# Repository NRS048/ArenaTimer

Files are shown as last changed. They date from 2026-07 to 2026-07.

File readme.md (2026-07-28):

Below this point is likely AI generated, do not trust what is said, many physical features are promised on the PCB but are not at all implemented in the codebase. -N

---

# ⏱️ Event Match Timer & Lockout System

An open-source, ESP32-based event and match timer platform featuring wireless remote integration, with web interface.

---

## 🚀 Getting Started

### 1. Hardware Orientation & Powering
* **Orientation Flexibility:** The timer can be configured to operate in either horizontal orientation. If your mounting or power cable strategy requires it, you can flip the included hanging bracket to the opposite side and enable **Invert Display** in the web settings to route the power cable from above.
* **Power Requirements:** Connect the timer using the provided power supply. 
> ⚠️ **CRITICAL:** Only use **5V** power supplies capable of delivering at least **60W**. Applying a voltage higher than 5V will **permanently damage** the hardware.

### 2. Initial Wi-Fi & Web UI Setup
1. **Boot Sequence:** Upon power-up, the display initializes with dashes (`--:--`) and the border will blink, indicating it is attempting to connect to the last saved Wi-Fi network.
2. **Access Point (AP) Mode:** If the network is unavailable (or during first-time setup), the timer switches to AP mode, broadcasting its own network:
   * **SSID:** `MACROTimer`
   * **Password:** `MACROTimerPassword`
   * Example Username & Password
3. **Connecting to the UI:** * Connect your phone, tablet, or computer to the `TimerSetup` network.
   * Locate the timer's IP address in your device's network connection settings (this process varies by operating system).
   * Open a web browser and enter the IP address to access the control interface.

<p align="center">
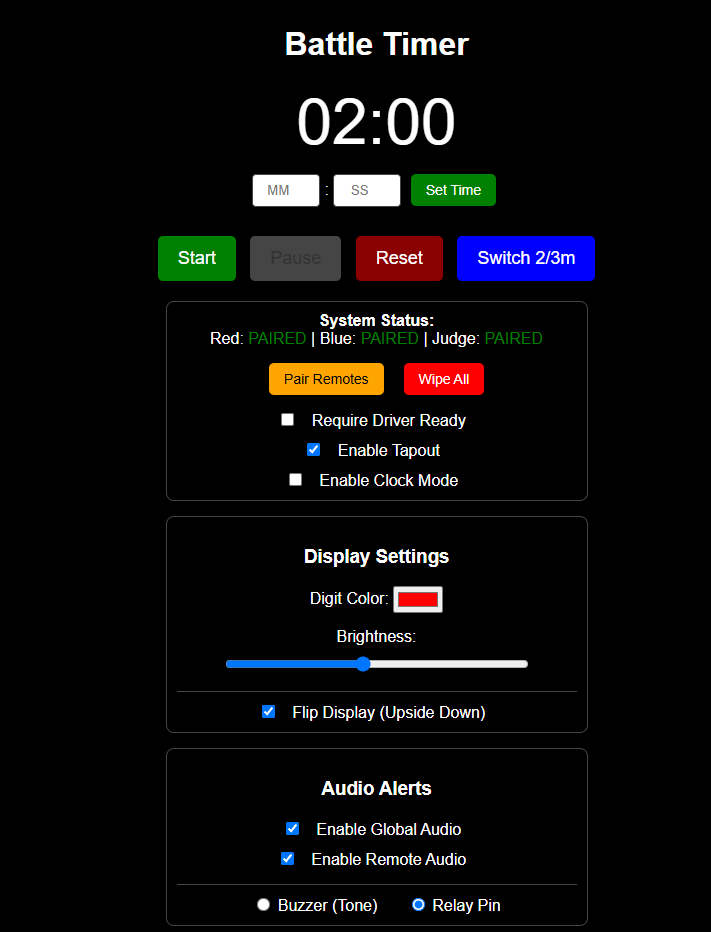
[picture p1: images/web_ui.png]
Web Control Interface Dashboard
  
</p>

*Note: The local AP interface is identical to the network interface. If no external Wi-Fi network is available at your venue, you can run the timer in this standalone mode completely offline.*

4. **Station Mode (Optional):** To connect the timer to an existing venue Wi-Fi network, use the configuration section at the bottom of the webpage to save your local **SSID** and **Password**.

<p align="center">
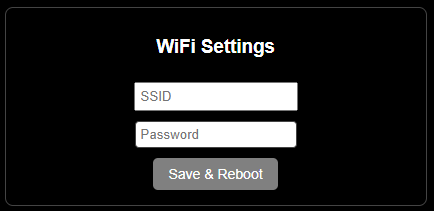
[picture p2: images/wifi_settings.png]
  
</p>

---

## ⚙️ Configuration & Features

### 🎮 Wireless Remotes & Pairing
The system supports three battery-powered wireless remotes: **one Main Controller** and **two Driver Ready/Tap-Out buttons** (Red vs. Blue).

<p align="center">
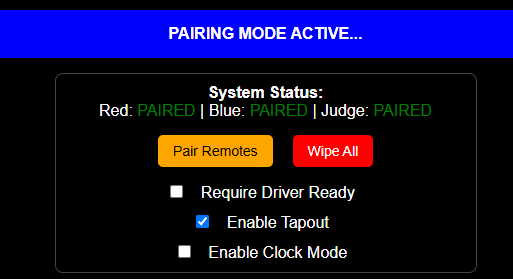
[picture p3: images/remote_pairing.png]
  
</p>

* **Pairing Procedure:** Remotes must be paired before deployment. Click **Pair Remote** in the Web UI to enter binding mode, turn on the remote, and press any button. The timer will automatically exit binding mode, and the Web UI status will update to `Paired`. Repeat independently for each remote.
* **Driver Ready Lockout:** Enabling the `Require Driver Ready` checkbox prevents a match from starting until both driver remotes register a "Ready" state. 
  * *Visual Indicators:* The physical white border indicates overall readiness. Individual Red/Blue illumination confirms when each respective driver has ready-ed up.
* **Tap-Out Functionality:** Even if the pre-match lockout is disabled, the driver remotes function by default as tap-out indicators. Pressing them during a match triggers a unique tap-out animation and audio effect (can be toggled off via the checkbox).

### 🔊 Audio Options
* **Global Toggle:** Easily enable or disable all system audio via the web panel.
* **Output Routing:** Switch between the onboard piezo beeper or a dedicated **relay output** used to switch larger external horn circuits, PA systems, or specialized lighting.
* **Attention Horn:** The Main Controller features a dedicated button to manually trigger the sound effects to grab the attention of competitors or spectators.

### 🔒 Operational Lockout
To prevent accidental mid-match disruption, most configuration options, adjustments, and web buttons are **automatically disabled** while the timer is actively running.

---

## 🛠️ Assembly Process (Electronics Kits)

For users assembling the hardware from the DIY electronics kits, follow this general framework. Refer to the project `BOM.md` for exact hardware sizing, screw counts, and component sourcing links.

### 1. 3D Printed Frame Selection
Choose the frame variant that best fits your 3D printer's build volume:
* **Small Printers:** Cut down to fit standard build plates. Requires more assembly hardware and time but maximizes accessibility.
* **Medium Printers (H2s/H2d Optimized):** A balanced approach featuring lower part counts and optimized print times.
* **Large Printers:** Designed specifically for large-format platforms like the *Elegoo Orange Storm Giga*. 

### 2. Print Settings & Materials
* **Main Frame:** Print in **PETG** for superior mechanical strength and thermal resilience during high-temperature transport or storage.
  * **Walls:** 4–6 perimeters
  * **Infill:** 15–25% Gyroid
* **Lenses:** All frame variations share the same lens files. Print them with enough top/bottom layers to ensure the front face prints **completely solid** to optimize light diffusion and visual clarity.

---

## 🧠 Advanced Development & Limitations

### 📡 RF Limitations & Best Practices
The timer utilizes an **ESP32** module with a printed trace antenna, while the remotes utilize **ESP8266** modules (also with printed antennas). 
* **Range & Interference:** While highly reliable in tested arena layouts (e.g., SEMO), performance can degrade at extreme distances or in environments experiencing heavy 2.4 GHz spectrum congestion (crowded Wi-Fi, heavy radio traffic).
* **Upgrades:** If your venue demands extreme range, the hardware can be modified to use variants featuring external SMA antennas. Reach out if you need assistance engineering a solution.
* **Multi-Timer Sync:** You can pair a single set of remotes to multiple timers simultaneously by repeating the pairing process on each unit. A native web-based synchronization protocol is currently on the feature roadmap.

### 💻 Firmware Upgrades & Exposed I/O
* **Over-The-Air (OTA) Updates:** Firmware updates can be flashed seamlessly without opening the enclosure. Navigate to `http://<your-timer-ip>/update` to access the **ElegantOTA** interface, where you can drag-and-drop compiled `.bin` updates.
* **Hardware Expansion:** Additional I/O pins are deliberately exposed near the internal ESP32 module. Advanced users can open the case and solder directly to these lines to integrate custom addressable LED strips, sensors, or physical inputs.

### ⚡ ESD Precautions & LED Repair
> ⚡ **CAUTION:** The internal PCBs contain components sensitive to Electrostatic Discharge (ESD). Handle bare board assemblies with care during assembly or modifications.

* **Common Failure Mode:** If an ESD event occurs, a single addressable LED in the display chain may burn out. Because the LEDs are wired in series, **if one LED fails, all subsequent data down the chain is blocked**, causing the rest of the display past that point to drop out. 
* **Support:** If you experience an LED failure during assembly or firmware hacking, reach out—these are repairable, and I can guide you through jumping or replacing the compromised pixel. Note that failures have only occurred during loose bench development; fully enclosed units have proven resilient during regular live event usage.

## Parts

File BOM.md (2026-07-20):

# Bill of Materials (BOM)

This document contains the component lists for building the Double-Sided Timer, Single-Sided Timer, Driver Ready Remotes, and Timer Controller. 

*Note: For a **Single-Sided Timer**, you can use the Double-Sided BOM but simply cut the quantities for the display housing, lenses, hardware, and PCBs in half.*

---

## 1. Double-Sided Timer

### 3D Printed Parts
*   **Timer Housing Parts:** 2 full sets (1 set = 1 Left + 1 Right). *PETG recommended, but any material/color works.*
*   **Lenses:** 2 full sets. *PETG recommended for transparency. Each set includes 4 digits, 4 borders, and 2 colons.*
*   **Joiner Blocks:** 4x
*   **Mounting Bracket:** 1x (Optional)

### Hardware & Mechanical
| Component | Qty | Notes / Link |
| :--- | :---: | :--- |
| PCB Mounting Screws | 24+ | 12 per side minimum. [Amazon](https://a.co/d/00hEOAHO) |
| Housing Screws for Joiner Blocks | 16-24 | [Amazon](https://a.co/d/06CnOLYg) |

### Electronics & PCBA
The system uses **4 Display PCBs** ordered from JLCPCB (Black solder mask, full assembly per the PCB BOM found in the `hardware` folder). 

**Only 1 of the 4 PCBs needs to be fully populated** with the ESP32, relay, beeper, screw terminals, and power connector based on your needs. The audio/relay parts are completely optional.

| Component | Qty | Description / Source |
| :--- | :---: | :--- |
| **ESP32 Development Board** | 1 | Main controller board. [Amazon](https://a.co/d/0hX7Juhc) |
| **Power Connector** | 1 | Same Sky PJ-082BH. [DigiKey](https://www.digikey.com/en/products/detail/same-sky-formerly-cui-devices/PJ-082BH/3477156) |
| **AC/DC Power Adapter** | 1 | 5V, 60W minimum. [Amazon](https://a.co/d/0fynI0mL) |
| **Beeper** (Optional) | 1 | Same Sky CEM-1203-42. [DigiKey](https://www.digikey.com/en/products/detail/same-sky-formerly-cui-devices/CEM-1203-42/412412) |
| **Relay** (Optional) | 1 | Omron/Aratas G5V-2-DC5. [DigiKey](https://www.digikey.com/en/products/detail/aratas-america-llc/G5V-2-DC5/87819) |
| **Screw Terminals** (Optional) | Var | For relay output. Phoenix Contact [socket](https://www.digikey.com/en/products/detail/phoenix-contact/1757255/260475) or [plug](https://www.digikey.com/en/products/detail/phoenix-contact/1757022/260380) |
| **16 AWG Wire** | ~2 ft | For connecting power between the two display sides. |
| **22 AWG Wire** | ~2 ft | For routing signals (`BOUT` > `BIN`, `DOUT` > `DIN`) to the second board. |

---

## 2. Driver Ready Remotes (Qty: 2)

The remote PCBAs are ordered as bare boards. To save costs, manually solder the headers/sockets that come included with the ESP8266 boards. The button circuit is simple and just shorts the `RST` pin of the ESP8266 to ground—this can easily be adapted to larger arcade buttons if desired.

### 3D Printed Parts
*   **Printed Housing:** 2x
*   **Printed Rear Cover:** 2x

### Components
| Component | Qty | Description / Source |
| :--- | :---: | :--- |
| **ESP8266 Board** | 2 | NodeMCU / D1 Mini style. [Amazon](https://a.co/d/02HlLmq1) |
| **Tactile Buttons** | 2 | Same Sky TS14-1212. [DigiKey](https://www.digikey.com/en/products/detail/same-sky-formerly-cui-devices/TS14-1212-120-BK-260-SCR-D/16562671) |
| **Button PCBs** | 2 | Custom bare boards (or custom wiring setup). |
| **Battery Pack** | 2 | Portable power source. [Amazon](https://a.co/d/02QkeaG8) |

---

## 3. Timer Controller

The controller PCBA uses the custom PCB fabrications ordered bare from JLCPCB using the Gerber files located in the `hardware` folder.

### 3D Printed Parts
*   **Printed Housing:** 1x
*   **Printed Rear Cover:** 1x

### Components
| Component | Qty | Description / Source |
| :--- | :---: | :--- |
| **ESP8266 Board** | 1 | NodeMCU / D1 Mini style. [Amazon](https://a.co/d/02HlLmq1) |
| **Tactile Buttons** | 5 | Same Sky TS14-1212. [DigiKey](https://www.digikey.com/en/products/detail/same-sky-formerly-cui-devices/TS14-1212-120-BK-260-SCR-D/16562671) |
| **Controller PCB** | 1 | Custom bare board. |
| **Battery Pack** | 1 | Portable power source. [Amazon](https://a.co/d/02QkeaG8) |

---

## 4. Range Upgrades & Modifications (Optional)

If you need extended wireless range for large track configurations, consider the following modifications:

*   **2.4GHz External Antenna (Untested):** Swap out the standard ESP8266 for a [Wemos D1 Mini Pro with an external antenna connector](https://www.aliexpress.us/item/3256808837639555.html).
*   **LoRA Conversion:** If 2.4GHz ESP-NOW performance is insufficient for your environment, the system can be adapted to LoRA hardware, though this will require additional custom hardware and firmware modifications.

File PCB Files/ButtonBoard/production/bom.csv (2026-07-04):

Designator | Footprint | Quantity | Value | LCSC Part #
D1 | 0603 | 1 | Red | C2286
J1, J2 | PinSocket_1x08_P2.54mm_Vertical | 2 | Conn_01x08_Socket | C42431840
J9 | 2060-452_998-404 | 1 | WAGO | C2765055
R1 | 0603 | 1 | 470 | C23179
SW1 | SW_PUSH-12mm | 1 | START | C2888699
SW2 | SW_PUSH-12mm | 1 | PAUSE | C2888699
SW3 | SW_PUSH-12mm | 1 | RESET | C2888699
SW4 | SW_PUSH-12mm | 1 | TIME_SEL | C2888699
SW5 | SW_PUSH-12mm | 1 | BUZZER | C2888699

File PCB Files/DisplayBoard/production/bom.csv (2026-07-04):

Designator | Footprint | Quantity | Value | LCSC Part #
C1, C2, C3, C4, C5, C6, C7 | 0402 | 7 | 100nF | C14663
D1, D10, D11, D112, D113, D114, D115, D116, D117, D118, D12, D13, D14, D15, D154, D155, D156, D157, D158, D159, D16, D160, D17, D18, D19, D2, D20, D21, D22, D23, D238, D239, D24, D240, D241, D242, D243, D244, D245, D246, D247, D248, D249, D25, D250, D251, D252, D253, D254, D255, D256, D257, D258, D259, D26, D260, D261, D262, D263, D264, D265, D266, D267, D268, D269, D27, D270, D271, D272, D273, D274, D275, D276, D277, D278, D279, D28, D280, D281, D282, D283, D284, D285, D286, D287, D288, D289, D29, D290, D291, D292, D293, D294, D295, D296, D297, D298, D299, D3, D30, D300, D301, D302, D303, D304, D305, D306, D307, D308, D309, D31, D310, D311, D312, D313, D314, D315, D316, D317, D318, D319, D32, D320, D321, D322, D323, D324, D325, D326, D327, D328, D329, D33, D330, D331, D332, D333, D334, D335, D336, D337, D338, D339, D34, D340, D341, D342, D35, D36, D37, D38, D4, D5, D6, D7, D70, D71, D72, D73, D74, D75, D76, D77, D78, D79, D8, D80, D81, D82, D83, D9 | LED_WS2812B_PLCC4_5.0x5.0mm_P3.2mm | 171 | WS2812B | C2843785
D40 | D_SMA | 1 | 1N1007, SMA | C727081
D41 | D_SOD-323 | 1 | 1N4148WS, SOD323 | C2128
J1 | JST_EH_S2B-EH_1x02_P2.50mm_Horizontal | 1 | Blue ready-up | C19271377
J10 | JST_EH_S2B-EH_1x02_P2.50mm_Horizontal | 1 | Red ready-up | C19271377
J13, J14 | 2060-452_998-404 | 2 | WAGO | C2765055
J15, J16 | PinSocket_1x15_P2.54mm_Vertical | 2 | Conn_01x15_Socket | C124408
J2 | PinSocket_1x02_P2.54mm_Horizontal | 1 | Conn_01x02_Socket | C2897384
J3 | PinHeader_1x02_P2.54mm_Horizontal | 1 | Conn_01x02_Pin | C492410
J4 | PinHeader_1x04_P2.54mm_Horizontal | 1 | GND | C492412
J5 | PinHeader_1x04_P2.54mm_Horizontal | 1 | 5V | C492412
J6 | PinSocket_1x04_P2.54mm_Horizontal | 1 | GND | C2897386
J7 | PinSocket_1x04_P2.54mm_Horizontal | 1 | 5V | C2897386
J9 | JST_EH_S6B-EH_1x06_P2.50mm_Horizontal | 1 | Conn_01x06_Pin | C157919
Q1, Q2 | SOT-323_SC-70 | 2 | BSS138 | C5224267
R10, R2 | 0402 | 2 | 100K | C25530
R3, R4, R5, R6, R7, R8, R9 | 0402 | 7 | 10k | C25744

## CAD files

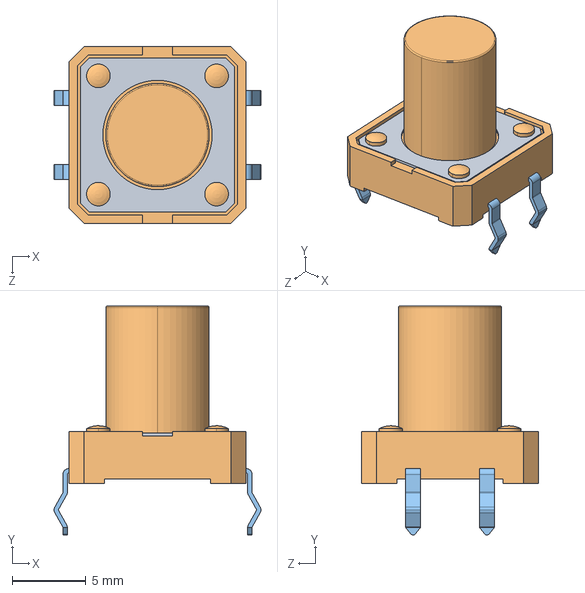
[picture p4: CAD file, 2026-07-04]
PCB Files/ButtonBoard/Same_Sky_TS14-1212-120-BK-260-SCR-D.step
14.0 x 15.5 x 12.0 mm

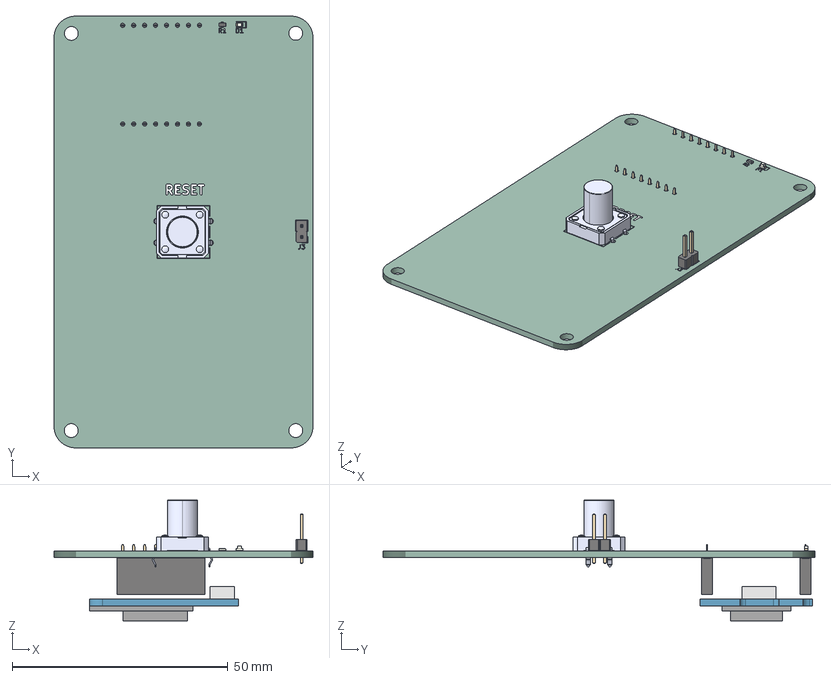
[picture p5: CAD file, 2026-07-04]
PCB Files/ReadyButtonBoard/ReadyButtonBoard.step
60.0 x 100.0 x 28.0 mm
PinHeader_1x02_P254mm_Vertical
LED_0603_1608Metric
CUI_DEVICES_TS14-1212-120-BK-260-SCR-D
R_0603_1608Metric
PinSocket_1x08_P2.54mm_Vertical x 2
wemos_d1_mini_light
ReadyButtonBoard_silkscreen x 2
ReadyButtonBoard_PCB

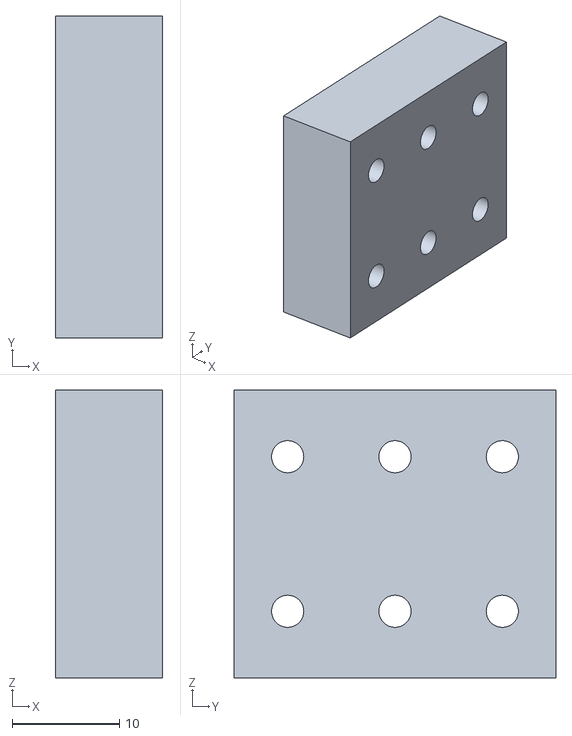
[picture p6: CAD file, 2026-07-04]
Print Files and Cad/Housing/Large Printer/Double_sided_mount.stl
10.00 x 30.0 x 26.8

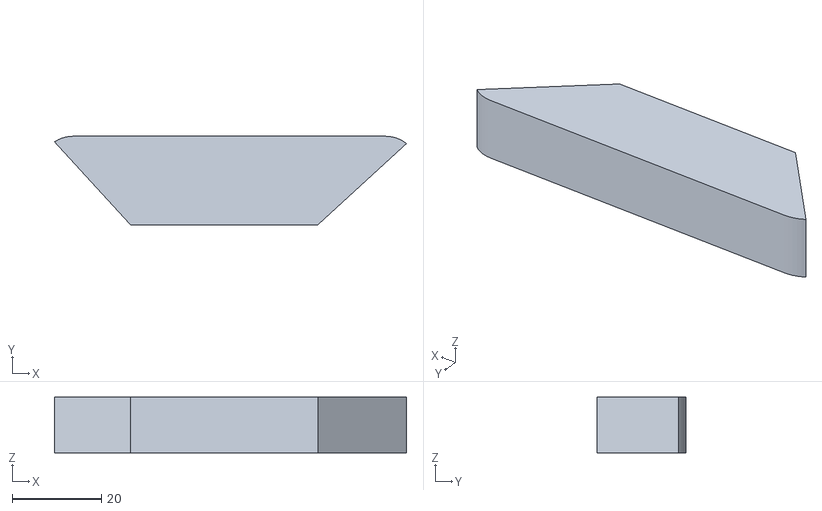
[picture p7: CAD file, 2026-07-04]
Print Files and Cad/Housing/Large Printer/Lenses/seg_d.stl
78.7 x 19.8 x 12.5

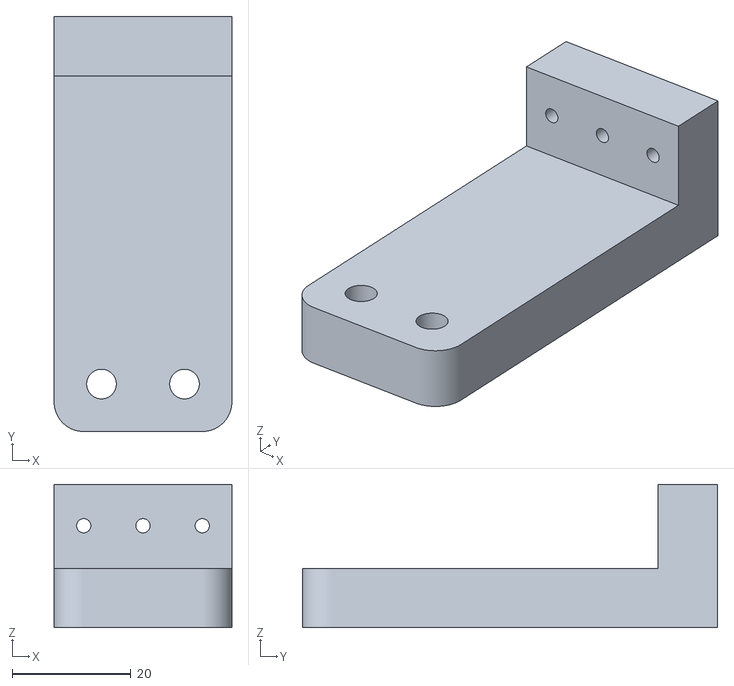
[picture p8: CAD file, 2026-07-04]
Print Files and Cad/Housing/Small Printer/Hanging_mount.stl
30.0 x 70.0 x 24.2

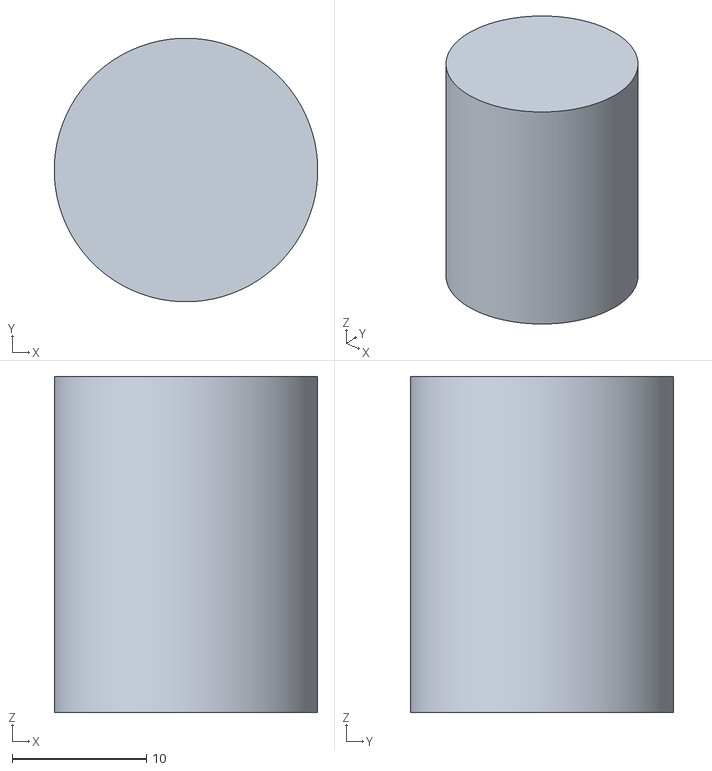
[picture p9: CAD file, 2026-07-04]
Print Files and Cad/Housing/Small Printer/Lenses/Colon_lens.stl
19.6 x 19.6 x 25.0

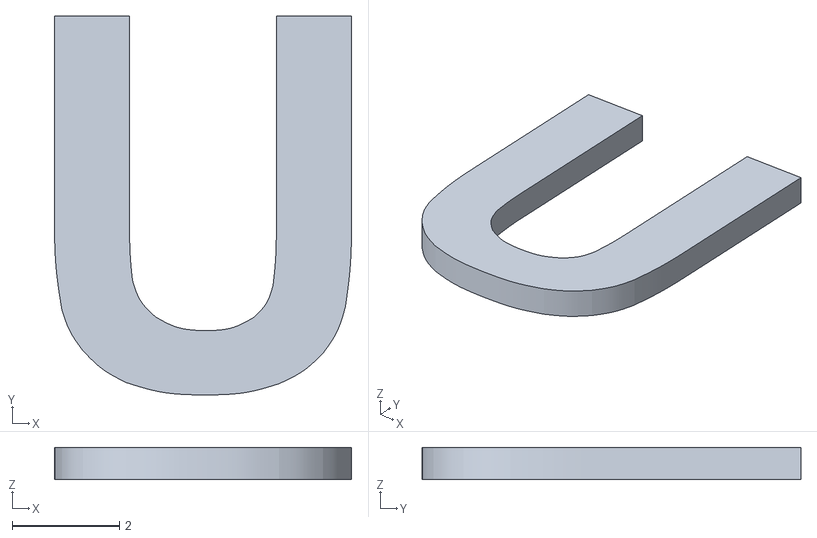
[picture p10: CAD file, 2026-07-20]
Print Files and Cad/Remotes/Controller/Timer Remote v22_Timer Remote v22_Body16.stl
5.54 x 7.06 x 0.6

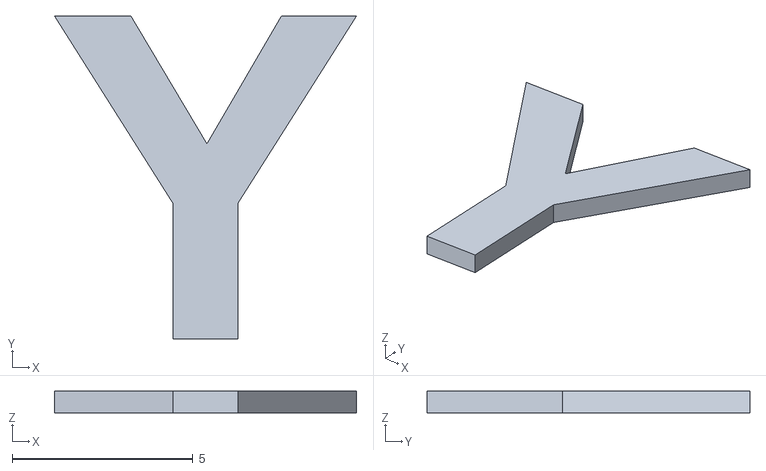
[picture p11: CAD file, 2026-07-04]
Print Files and Cad/Remotes/Driver Ready/Driver Ready Remote v2_Driver Ready Remote v2_Body19.stl
8.35 x 8.93 x 0.6

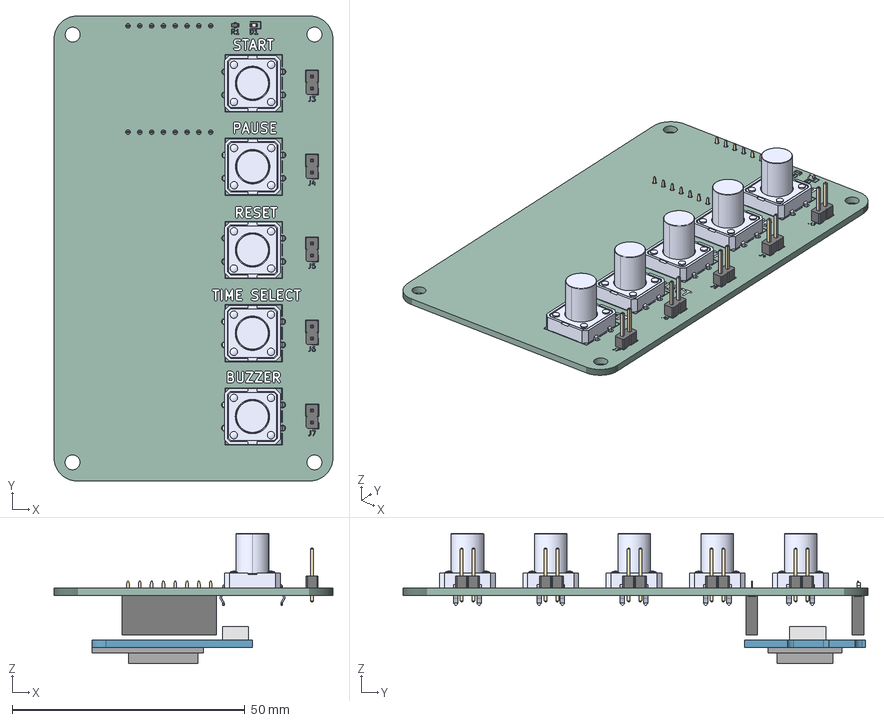
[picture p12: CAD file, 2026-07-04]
PCB Files/ButtonBoard/ButtonBoard.step
60.0 x 100.0 x 28.0 mm
PinHeader_1x02_P254mm_Vertical x 5
CUI_DEVICES_TS14-1212-120-BK-260-SCR-D x 5
LED_0603_1608Metric
R_0603_1608Metric
PinSocket_1x08_P2.54mm_Vertical x 2
wemos_d1_mini_light
ButtonBoard_silkscreen x 2
ButtonBoard_PCB

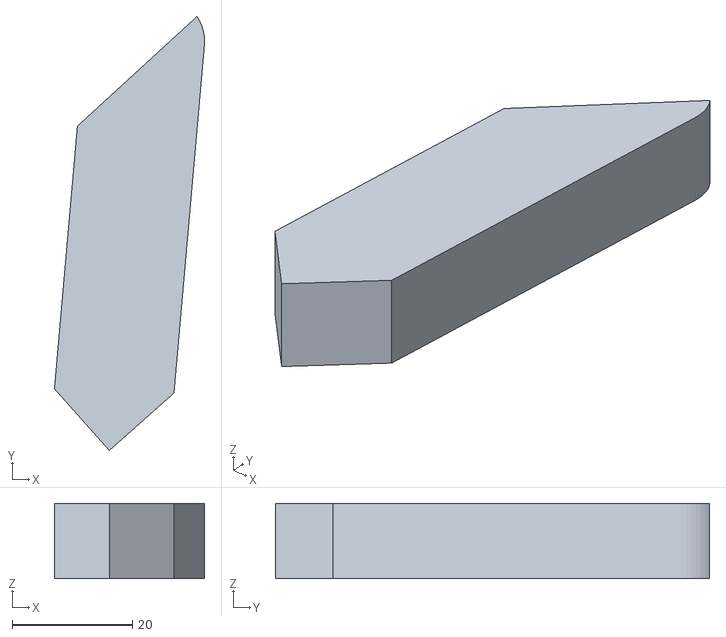
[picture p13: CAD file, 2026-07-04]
Print Files and Cad/Housing/Large Printer/Lenses/seg_e.stl
25.0 x 72.3 x 12.5

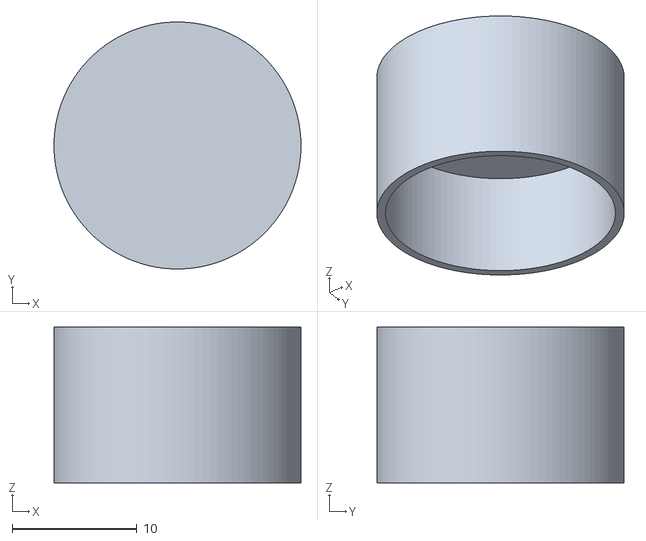
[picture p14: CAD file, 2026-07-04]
Print Files and Cad/Housing/Medium Printer/Lenses/colon.stl
19.8 x 19.8 x 12.5

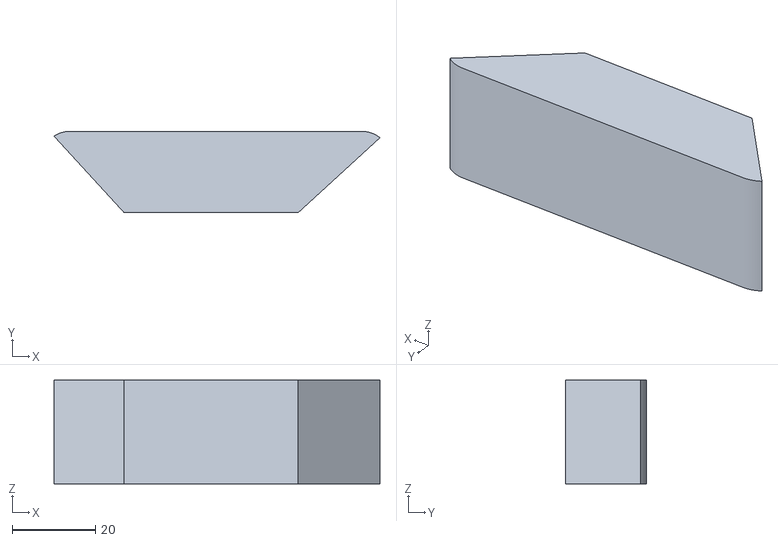
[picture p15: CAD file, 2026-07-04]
Print Files and Cad/Housing/Small Printer/Lenses/seg_d.stl
78.4 x 19.6 x 25.0

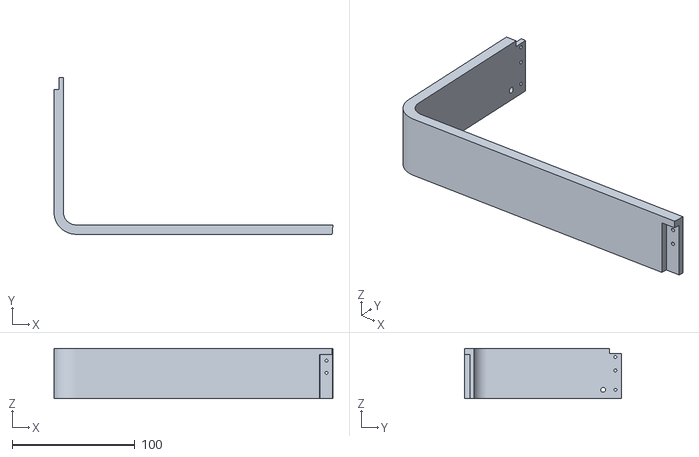
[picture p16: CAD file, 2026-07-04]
Print Files and Cad/Housing/Small Printer/Top_right.stl
227.7 x 127.8 x 41.0

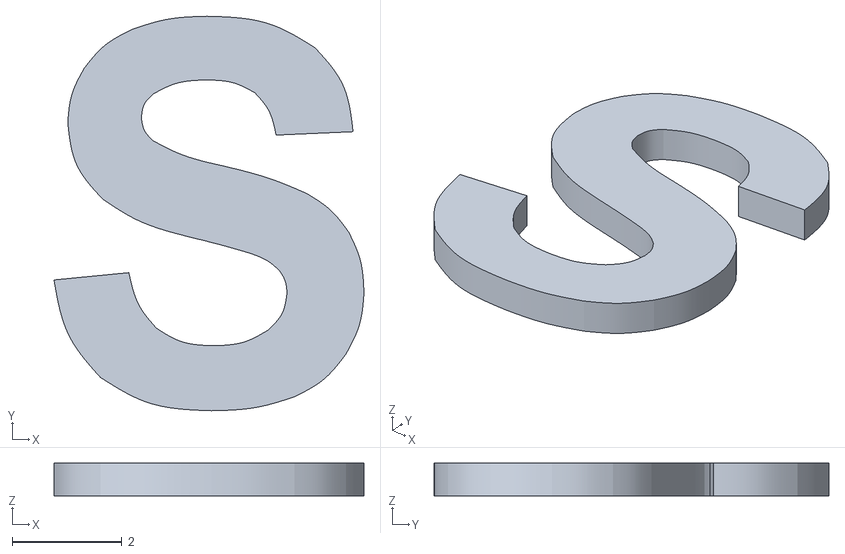
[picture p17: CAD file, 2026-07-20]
Print Files and Cad/Remotes/Controller/Timer Remote v22_Timer Remote v22_Body19.stl
5.65 x 7.18 x 0.6

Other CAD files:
Print Files and Cad/Housing/Medium Printer/Lenses/seg_a.stl
Print Files and Cad/Remotes/Driver Ready/Driver Ready Remote v2_Driver Ready Remote v2_Body29.stl
Print Files and Cad/Housing/Large Printer/Lenses/bottom_right.stl
Print Files and Cad/Housing/Large Printer/Lenses/bottom_left.stl
Print Files and Cad/Housing/Large Printer/Lenses/seg_a.stl
Print Files and Cad/Housing/Large Printer/Lenses/seg_b.stl
Print Files and Cad/Housing/Large Printer/Lenses/seg_c.stl
Print Files and Cad/Housing/Large Printer/Lenses/seg_f.stl
Print Files and Cad/Housing/Large Printer/Lenses/seg_g.stl
Print Files and Cad/Housing/Large Printer/Lenses/top_left.stl
Print Files and Cad/Housing/Large Printer/Lenses/top_right.stl
Print Files and Cad/Housing/Medium Printer/Lenses/bottom_left.stl
Print Files and Cad/Housing/Medium Printer/Lenses/bottom_right.stl
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

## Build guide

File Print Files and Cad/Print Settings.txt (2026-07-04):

All frame parts - 4-5 walls, 10-20% infill
Lenses 5mm solid bottom skin diffuses the best, 1-wall on bottom layer

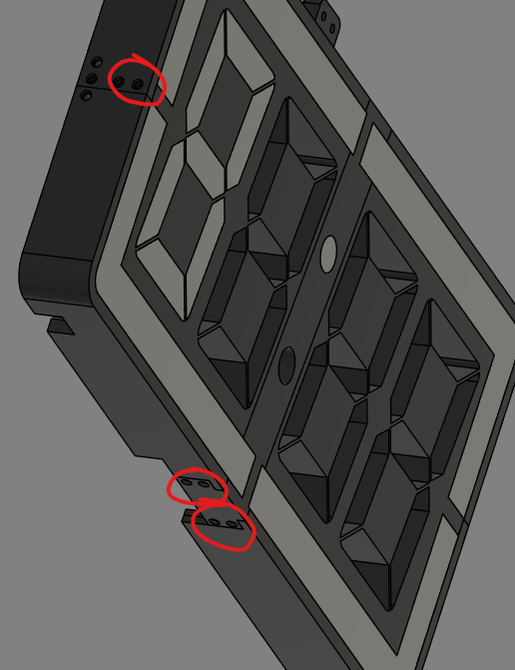
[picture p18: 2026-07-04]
Print Files and Cad/Housing/Small Printer/Assembly/img4.png

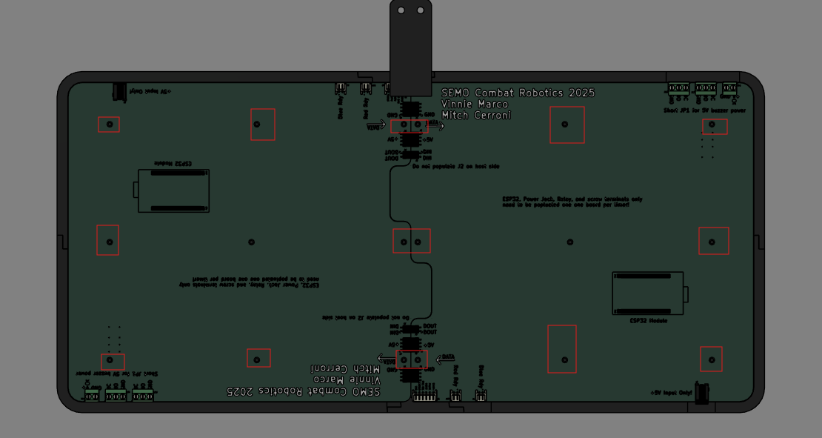
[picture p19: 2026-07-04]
Print Files and Cad/Housing/Small Printer/Assembly/img2.png

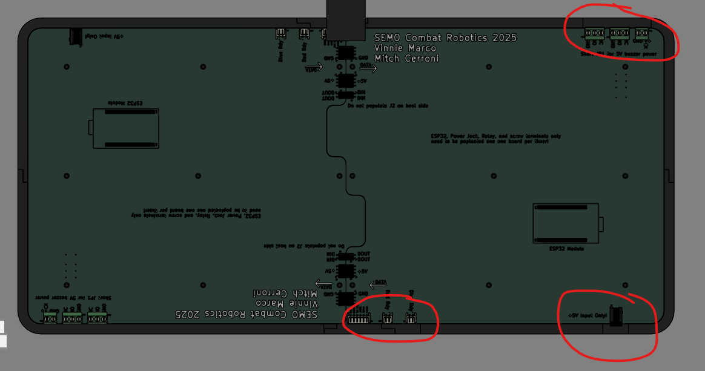
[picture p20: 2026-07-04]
Print Files and Cad/Housing/Small Printer/Assembly/img5.png

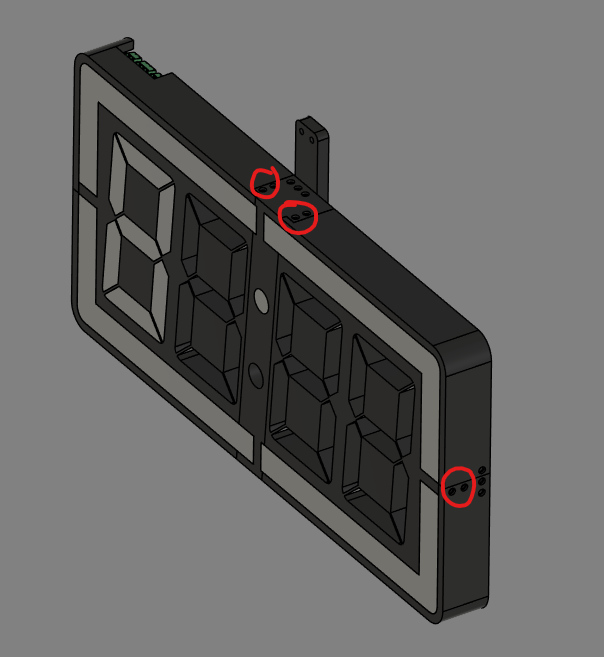
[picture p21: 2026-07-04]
Print Files and Cad/Housing/Small Printer/Assembly/img3.png

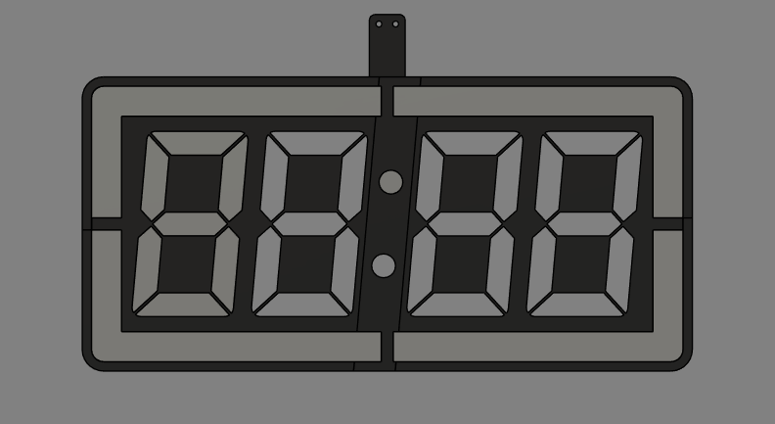
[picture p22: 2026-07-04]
Print Files and Cad/Housing/Small Printer/Assembly/img1.png

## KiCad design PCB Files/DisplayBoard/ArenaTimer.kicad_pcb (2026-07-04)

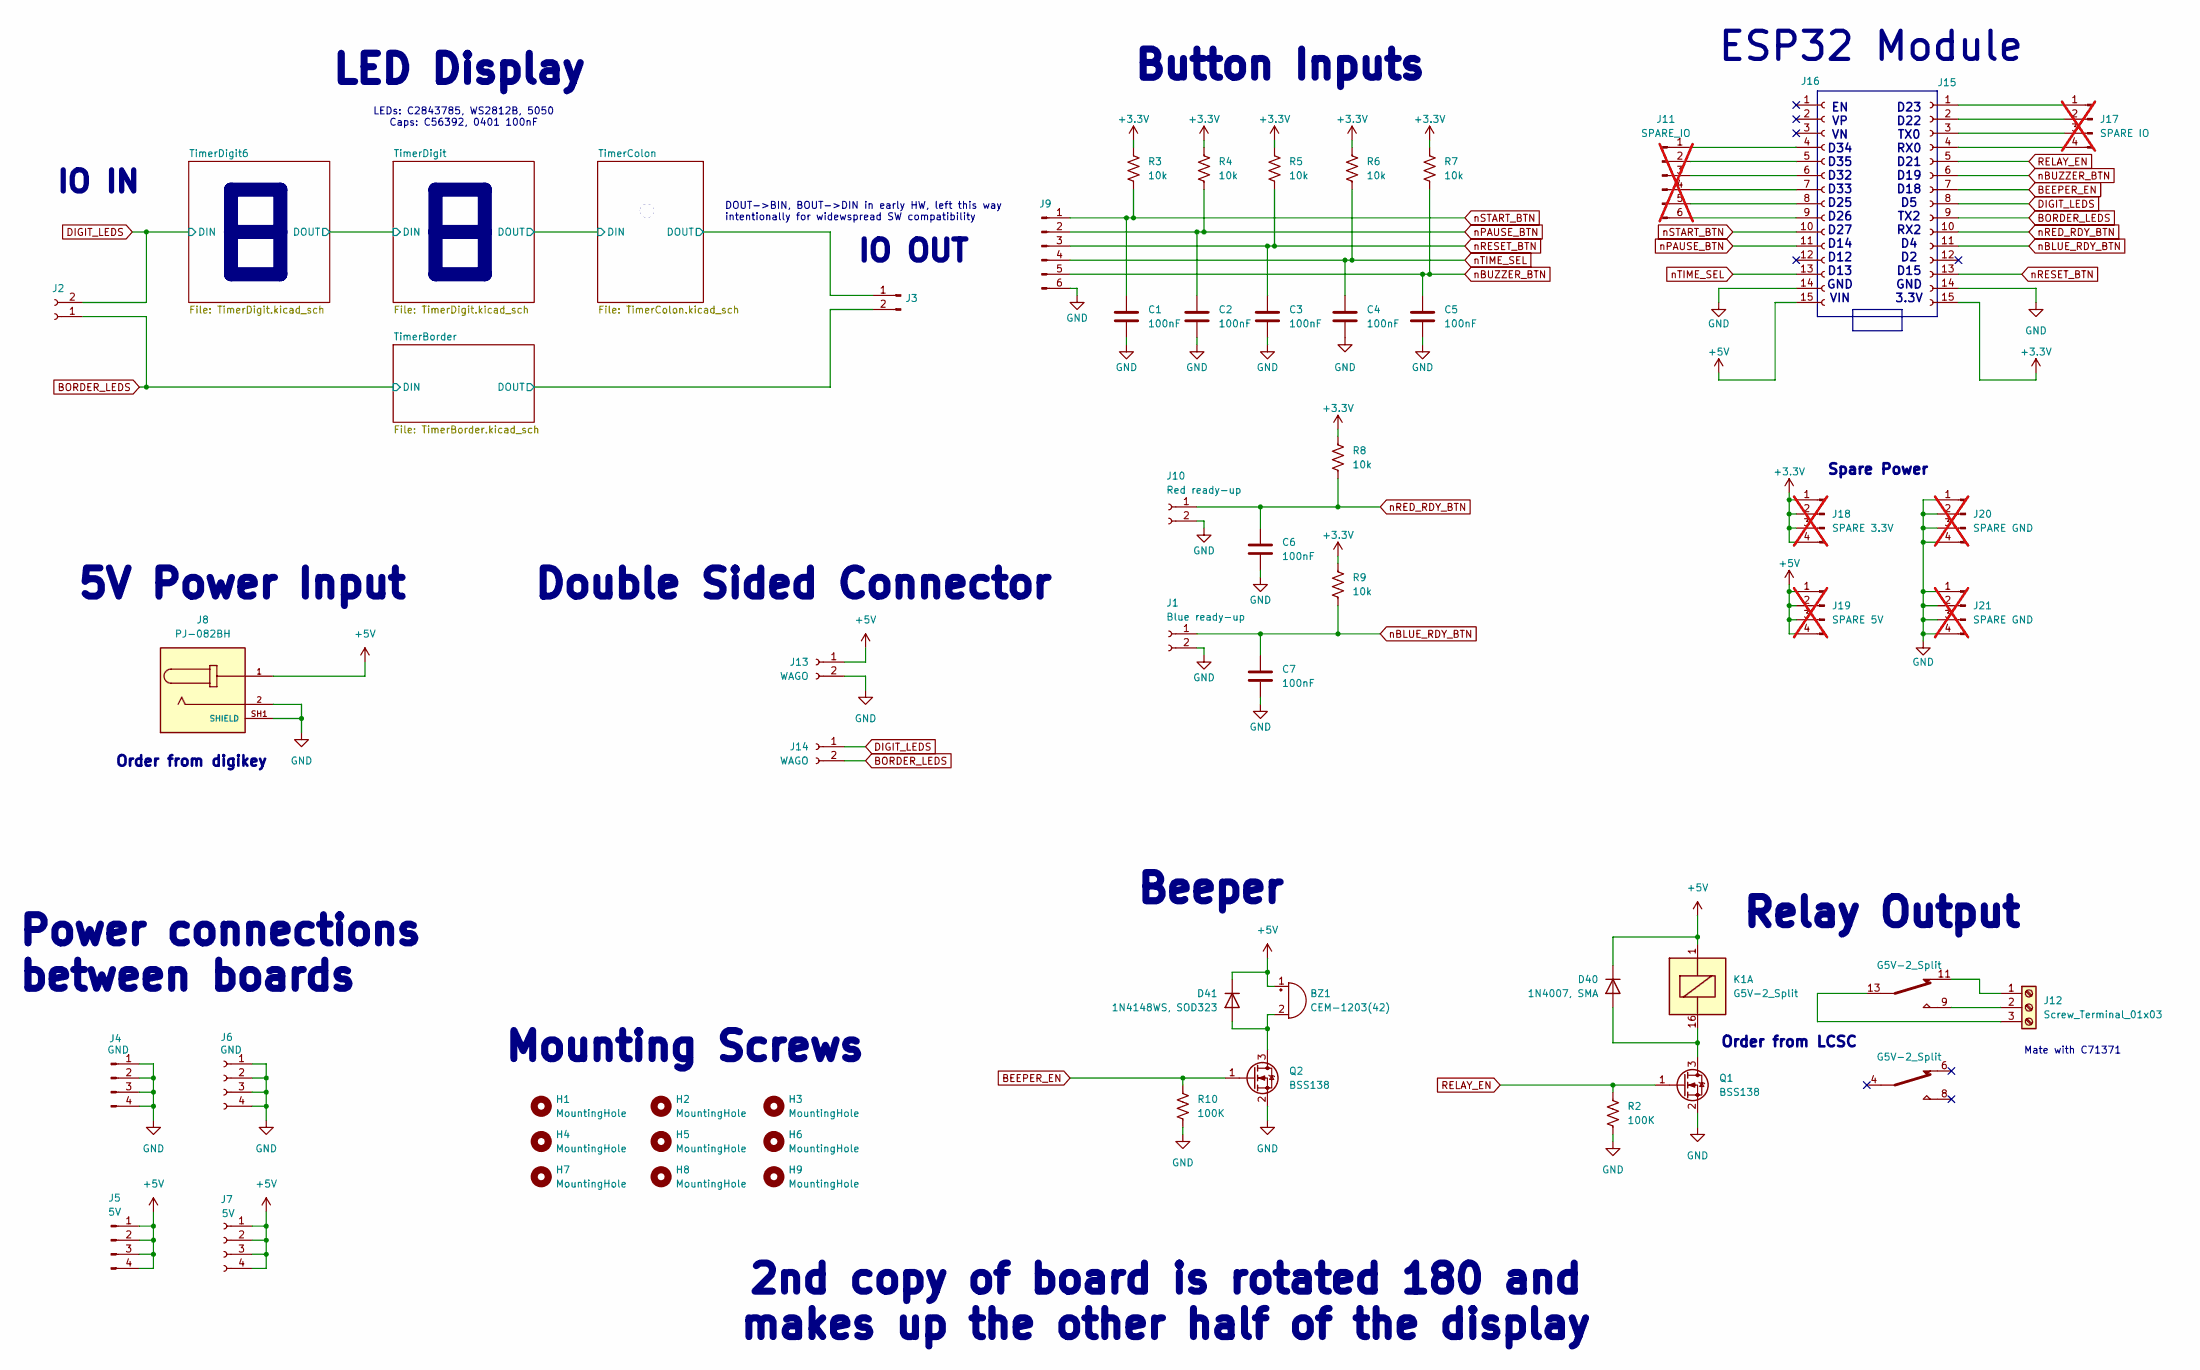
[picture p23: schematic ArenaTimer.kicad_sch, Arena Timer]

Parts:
BZ1: CEM-1203(42); Buzzer_TDK_PS1240P02BT_D12.2mm_H6.5mm; LCSC C3812098
C1, C2, C3, C4, C5, C6, C7: 100nF; C_0402_1005Metric; LCSC C1581
D40: 1N4007, SMA; D_SMA; LCSC C727081
D41: 1N4148WS, SOD323; D_SOD-323; LCSC C2128
H1, H2, H3, H4, H5, H6, H7, H8, H9: MountingHole; MountingHole_3.2mm_M3
J1: Blue ready-up; JST_EH_S2B-EH_1x02_P2.50mm_Horizontal; LCSC C19271377
J2: Conn_01x02_Socket; PinSocket_1x02_P2.54mm_Horizontal; LCSC C2897384
J3: Conn_01x02_Pin; PinHeader_1x02_P2.54mm_Horizontal; LCSC C492410
J4: GND; PinHeader_1x04_P2.54mm_Horizontal; LCSC C492412
J5: 5V; PinHeader_1x04_P2.54mm_Horizontal; LCSC C492412
J6: GND; PinSocket_1x04_P2.54mm_Horizontal; LCSC C2897386
J7: 5V; PinSocket_1x04_P2.54mm_Horizontal; LCSC C2897386
J8: PJ-082BH; SAMESKY_PJ-082BH; PARTREV 1.06; LCSC C3094233
J9: Conn_01x06_Pin; JST_EH_S6B-EH_1x06_P2.50mm_Horizontal; LCSC C157919
J10: Red ready-up; JST_EH_S2B-EH_1x02_P2.50mm_Horizontal; LCSC C19271377
J11: SPARE_IO; PinHeader_1x06_P2.54mm_Vertical; not fitted
J12: Screw_Terminal_01x03; TerminalBlock_MaiXu_MX126-5.0-03P_1x03_P5.00mm; LCSC C8377
J13, J14: WAGO; 2060-452_998-404; LCSC C2765055
J15, J16: Conn_01x15_Socket; PinSocket_1x15_P2.54mm_Vertical; LCSC C124408
J17: SPARE IO; PinHeader_1x04_P2.54mm_Vertical; not fitted
J18: SPARE 3.3V; PinHeader_1x04_P2.54mm_Vertical; not fitted
J19: SPARE 5V; PinHeader_1x04_P2.54mm_Vertical; not fitted
J20, J21: SPARE GND; PinHeader_1x04_P2.54mm_Vertical; not fitted
K1: G5V-2_Split; Relay_DPDT_Omron_G5V-2; LCSC C27269
Q1, Q2: BSS138; SOT-323_SC-70; LCSC C5224279
R2, R10: 100K; R_0402_1005Metric; LCSC C25530
R3, R4, R5, R6, R7, R8, R9: 10k; R_0402_1005Metric; LCSC C25744

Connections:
+3.3V: J15.15, J18.1, J18.2, J18.3, J18.4, R3.1, R4.1, R5.1, R6.1, R7.1, R8.1, R9.1
+5V: BZ1.1 (+), D40.1 (K), D41.1 (K), J5.1, J5.2, J5.3, J5.4, J7.1, J7.2, J7.3, J7.4, J8.1, J13.1, J16.15, J19.1, J19.2, J19.3, J19.4, K1.1; also elsewhere on the board
/TimerBorder/DOUT: J3.2; also elsewhere on the board
/TimerColon/DOUT: J3.1; also elsewhere on the board
BEEPER_EN: J15.7, Q2.1 (G), R10.1
BORDER_LEDS: J2.1, J14.2, J15.9; also elsewhere on the board
DIGIT_LEDS: J2.2, J14.1, J15.8; also elsewhere on the board
GND: C1.2, C2.2, C3.2, C4.2, C5.2, C6.2, C7.2, J1.2, J4.1, J4.2, J4.3, J4.4, J6.1, J6.2, J6.3, J6.4, J8.2, J8.SH1 (SHIELD), J8.SH2 (SHIELD), J8.SH3 (SHIELD), J8.SH4 (SHIELD), J9.6, J10.2, J13.2, J15.14, J16.14, J20.1, J20.2, J20.3, J20.4, J21.1, J21.2, J21.3, J21.4, Q1.2 (S), Q2.2 (S), R2.2, R10.2; also elsewhere on the board
unnamed: BZ1.2 (-), D41.2 (A), Q2.3 (D)
unnamed: D40.2 (A), K1.16, Q1.3 (D)
unnamed: J11.1, J16.4
unnamed: J11.2, J16.5
unnamed: J11.3, J16.6
unnamed: J11.4, J16.7
unnamed: J11.5, J16.8
unnamed: J11.6, J16.9
unnamed: J12.1, K1.11
unnamed: J12.2, K1.9
unnamed: J12.3, K1.13
unnamed: J15.1, J17.1
unnamed: J15.2, J17.2
unnamed: J15.3, J17.3
unnamed: J15.4, J17.4
RELAY_EN: J15.5, Q1.1 (G), R2.1
nBLUE_RDY_BTN: C7.1, J1.1, J15.11, R9.2
nBUZZER_BTN: C5.1, J9.5, J15.6, R7.2
nPAUSE_BTN: C2.1, J9.2, J16.11, R4.2
nRED_RDY_BTN: C6.1, J10.1, J15.10, R8.2
nRESET_BTN: C3.1, J9.3, J15.13, R5.2
nSTART_BTN: C1.1, J9.1, J16.10, R3.2
nTIME_SEL: C4.1, J9.4, J16.13, R6.2

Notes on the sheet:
Spare Power
EN VP VN D34 D35 D32 D33 D25 D26 D27 D14 D12 D13 GND VIN
Order from digikey
Mate with C71371
IO IN
Beeper
Power connections between boards
5V Power Input
Order from LCSC
IO OUT
Double Sided Connector
2nd copy of board is rotated 180 and makes up the other half of the display
Relay Output
Button Inputs
Mounting Screws
D23 D22 TX0 RX0 D21 D19 D18 D5 TX2 RX2 D4 D2 D15 GND 3.3V
LEDs: C2843785, WS2812B, 5050 Caps: C56392, 0401 100nF
ESP32 Module
DOUT->BIN, BOUT->DIN in early HW, left this way intentionally for widewspread SW compatibility
LED Display

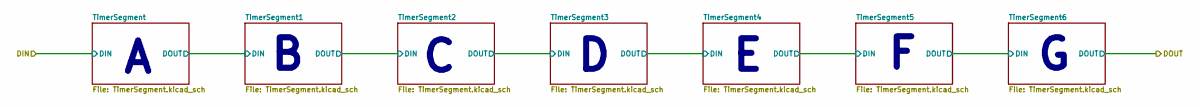
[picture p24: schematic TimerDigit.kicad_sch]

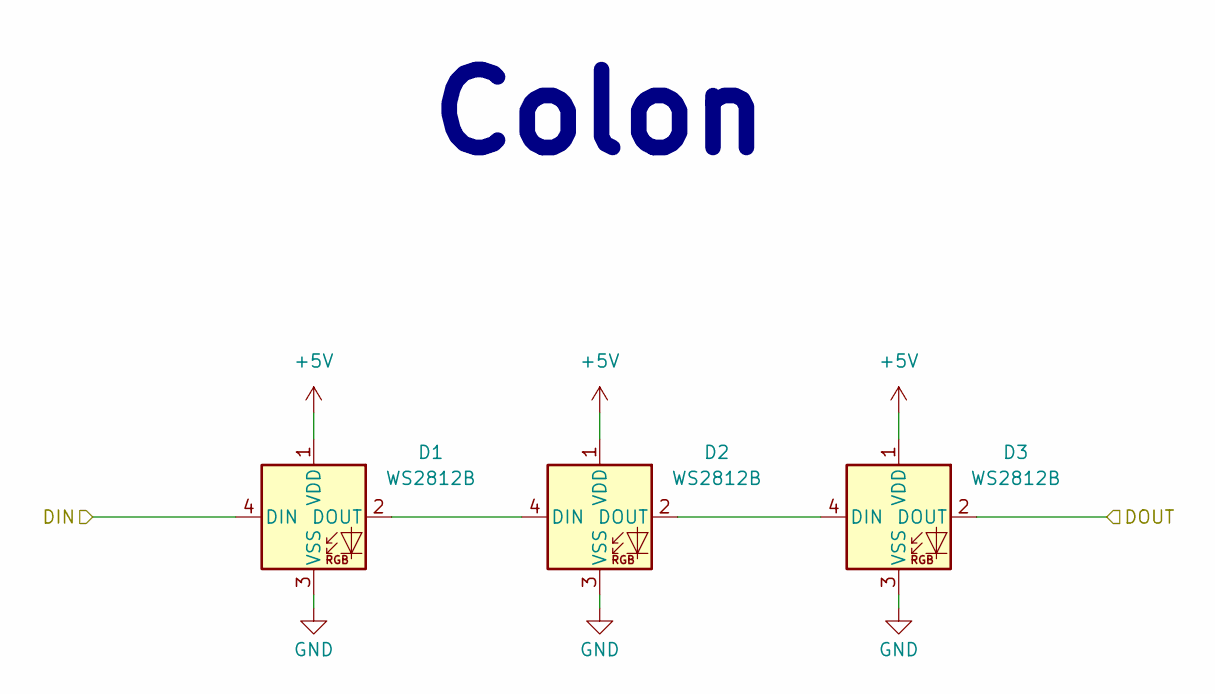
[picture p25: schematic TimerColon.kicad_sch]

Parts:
D1, D2, D3: WS2812B; LED_WS2812B_PLCC4_5.0x5.0mm_P3.2mm; LCSC C2843785

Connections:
+5V: D1.1 (VDD), D2.1 (VDD), D3.1 (VDD); also elsewhere on the board
/TimerColon/DIN: D1.4 (DIN); also elsewhere on the board
/TimerColon/DOUT: D3.2 (DOUT); also elsewhere on the board
GND: D1.3 (VSS), D2.3 (VSS), D3.3 (VSS); also elsewhere on the board
unnamed: D1.2 (DOUT), D2.4 (DIN)
unnamed: D2.2 (DOUT), D3.4 (DIN)

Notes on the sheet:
Colon

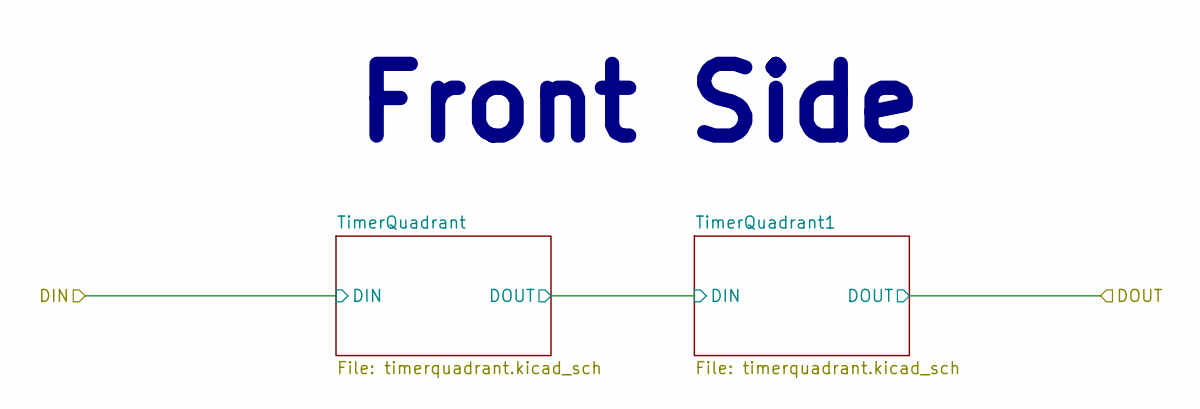
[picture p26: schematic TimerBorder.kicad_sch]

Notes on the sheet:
Front Side

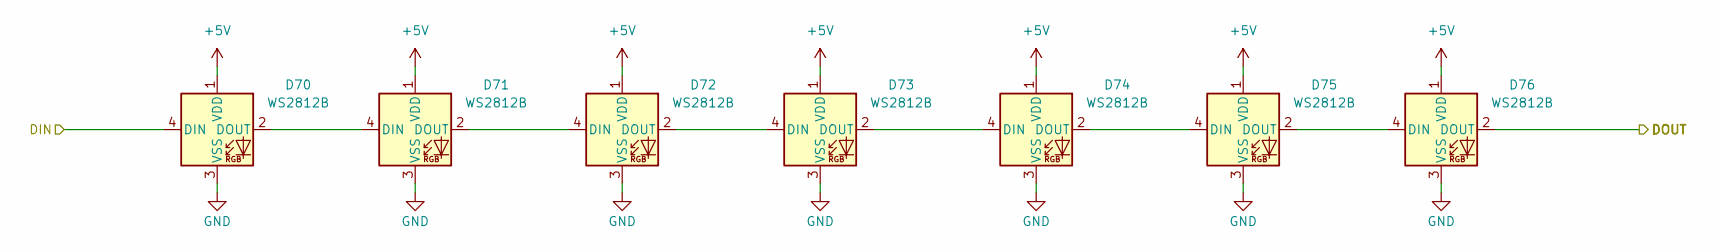
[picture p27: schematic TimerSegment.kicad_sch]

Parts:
D70, D71, D72, D73, D74, D75, D76: WS2812B; LED_WS2812B_PLCC4_5.0x5.0mm_P3.2mm; LCSC C2843785

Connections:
+5V: D70.1 (VDD), D71.1 (VDD), D72.1 (VDD), D73.1 (VDD), D74.1 (VDD), D75.1 (VDD), D76.1 (VDD); also elsewhere on the board
/TimerDigit/DIN: D70.4 (DIN); also elsewhere on the board
/TimerDigit/TimerSegment/DOUT: D76.2 (DOUT); also elsewhere on the board
GND: D70.3 (VSS), D71.3 (VSS), D72.3 (VSS), D73.3 (VSS), D74.3 (VSS), D75.3 (VSS), D76.3 (VSS); also elsewhere on the board
unnamed: D70.2 (DOUT), D71.4 (DIN)
unnamed: D71.2 (DOUT), D72.4 (DIN)
unnamed: D72.2 (DOUT), D73.4 (DIN)
unnamed: D73.2 (DOUT), D74.4 (DIN)
unnamed: D74.2 (DOUT), D75.4 (DIN)
unnamed: D75.2 (DOUT), D76.4 (DIN)

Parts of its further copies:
D77, D78, D79, D80, D81, D82, D83, D112, D113, D114, D115, D116, D117, D118, D154, D155, D156, D157, D158, D159, D160, D238, D239, D240, D241, D242, D243, D244, D245, D246, D247, D248, D249, D250, D251, D287, D288, D289, D290, D291, D292, D293, D294, D295, D296, D297, D298, D299, D300, D301, D302, D303, D304, D305, D306, D307, D308, D309, D310, D311, D312, D313, D314, D315, D316, D317, D318, D319, D320, D321, D322, D323, D324, D325, D326, D327, D328, D329, D330, D331, D332, D333, D334, D335, D336, D337, D338, D339, D340, D341, D342: WS2812B; LED_WS2812B_PLCC4_5.0x5.0mm_P3.2mm; LCSC C2843785

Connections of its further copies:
+5V: D77.1 (VDD), D78.1 (VDD), D79.1 (VDD), D80.1 (VDD), D81.1 (VDD), D82.1 (VDD), D83.1 (VDD), D112.1 (VDD), D113.1 (VDD), D114.1 (VDD), D115.1 (VDD), D116.1 (VDD), D117.1 (VDD), D118.1 (VDD), D154.1 (VDD), D155.1 (VDD), D156.1 (VDD), D157.1 (VDD), D158.1 (VDD), D159.1 (VDD), D160.1 (VDD), D238.1 (VDD), D239.1 (VDD), D240.1 (VDD), D241.1 (VDD), D242.1 (VDD), D243.1 (VDD), D244.1 (VDD), D245.1 (VDD), D246.1 (VDD), D247.1 (VDD), D248.1 (VDD), D249.1 (VDD), D250.1 (VDD), D251.1 (VDD), D287.1 (VDD), D288.1 (VDD), D289.1 (VDD), D290.1 (VDD), D291.1 (VDD), D292.1 (VDD), D293.1 (VDD), D294.1 (VDD), D295.1 (VDD), D296.1 (VDD), D297.1 (VDD), D298.1 (VDD), D299.1 (VDD), D300.1 (VDD), D301.1 (VDD), D302.1 (VDD), D303.1 (VDD), D304.1 (VDD), D305.1 (VDD), D306.1 (VDD), D307.1 (VDD), D308.1 (VDD), D309.1 (VDD), D310.1 (VDD), D311.1 (VDD), D312.1 (VDD), D313.1 (VDD), D314.1 (VDD), D315.1 (VDD), D316.1 (VDD), D317.1 (VDD), D318.1 (VDD), D319.1 (VDD), D320.1 (VDD), D321.1 (VDD), D322.1 (VDD), D323.1 (VDD), D324.1 (VDD), D325.1 (VDD), D326.1 (VDD), D327.1 (VDD), D328.1 (VDD), D329.1 (VDD), D330.1 (VDD), D331.1 (VDD), D332.1 (VDD), D333.1 (VDD), D334.1 (VDD), D335.1 (VDD), D336.1 (VDD), D337.1 (VDD), D338.1 (VDD), D339.1 (VDD), D340.1 (VDD), D341.1 (VDD), D342.1 (VDD); also elsewhere on the board
/TimerColon/DIN: D293.2 (DOUT); also elsewhere on the board
/TimerDigit6/TimerSegment1/DOUT: D308.4 (DIN), D342.2 (DOUT)
/TimerDigit6/TimerSegment2/DOUT: D301.4 (DIN), D314.2 (DOUT)
/TimerDigit6/TimerSegment3/DOUT: D294.4 (DIN), D307.2 (DOUT)
/TimerDigit6/TimerSegment4/DOUT: D300.2 (DOUT), D322.4 (DIN)
/TimerDigit6/TimerSegment5/DOUT: D315.4 (DIN), D328.2 (DOUT)
/TimerDigit6/TimerSegment/DOUT: D335.2 (DOUT), D336.4 (DIN)
/TimerDigit/DIN: D321.2 (DOUT); also elsewhere on the board
/TimerDigit/TimerSegment1/DOUT: D83.2 (DOUT), D112.4 (DIN)
/TimerDigit/TimerSegment2/DOUT: D118.2 (DOUT), D154.4 (DIN)
/TimerDigit/TimerSegment3/DOUT: D160.2 (DOUT), D238.4 (DIN)
/TimerDigit/TimerSegment4/DOUT: D244.2 (DOUT), D245.4 (DIN)
/TimerDigit/TimerSegment5/DOUT: D251.2 (DOUT), D287.4 (DIN)
/TimerDigit/TimerSegment/DOUT: D77.4 (DIN); also elsewhere on the board
DIGIT_LEDS: D329.4 (DIN); also elsewhere on the board
GND: D77.3 (VSS), D78.3 (VSS), D79.3 (VSS), D80.3 (VSS), D81.3 (VSS), D82.3 (VSS), D83.3 (VSS), D112.3 (VSS), D113.3 (VSS), D114.3 (VSS), D115.3 (VSS), D116.3 (VSS), D117.3 (VSS), D118.3 (VSS), D154.3 (VSS), D155.3 (VSS), D156.3 (VSS), D157.3 (VSS), D158.3 (VSS), D159.3 (VSS), D160.3 (VSS), D238.3 (VSS), D239.3 (VSS), D240.3 (VSS), D241.3 (VSS), D242.3 (VSS), D243.3 (VSS), D244.3 (VSS), D245.3 (VSS), D246.3 (VSS), D247.3 (VSS), D248.3 (VSS), D249.3 (VSS), D250.3 (VSS), D251.3 (VSS), D287.3 (VSS), D288.3 (VSS), D289.3 (VSS), D290.3 (VSS), D291.3 (VSS), D292.3 (VSS), D293.3 (VSS), D294.3 (VSS), D295.3 (VSS), D296.3 (VSS), D297.3 (VSS), D298.3 (VSS), D299.3 (VSS), D300.3 (VSS), D301.3 (VSS), D302.3 (VSS), D303.3 (VSS), D304.3 (VSS), D305.3 (VSS), D306.3 (VSS), D307.3 (VSS), D308.3 (VSS), D309.3 (VSS), D310.3 (VSS), D311.3 (VSS), D312.3 (VSS), D313.3 (VSS), D314.3 (VSS), D315.3 (VSS), D316.3 (VSS), D317.3 (VSS), D318.3 (VSS), D319.3 (VSS), D320.3 (VSS), D321.3 (VSS), D322.3 (VSS), D323.3 (VSS), D324.3 (VSS), D325.3 (VSS), D326.3 (VSS), D327.3 (VSS), D328.3 (VSS), D329.3 (VSS), D330.3 (VSS), D331.3 (VSS), D332.3 (VSS), D333.3 (VSS), D334.3 (VSS), D335.3 (VSS), D336.3 (VSS), D337.3 (VSS), D338.3 (VSS), D339.3 (VSS), D340.3 (VSS), D341.3 (VSS), D342.3 (VSS); also elsewhere on the board
unnamed: D77.2 (DOUT), D78.4 (DIN)
unnamed: D78.2 (DOUT), D79.4 (DIN)
unnamed: D79.2 (DOUT), D80.4 (DIN)
unnamed: D80.2 (DOUT), D81.4 (DIN)
unnamed: D81.2 (DOUT), D82.4 (DIN)
unnamed: D82.2 (DOUT), D83.4 (DIN)
unnamed: D112.2 (DOUT), D113.4 (DIN)
unnamed: D113.2 (DOUT), D114.4 (DIN)
unnamed: D114.2 (DOUT), D115.4 (DIN)
unnamed: D115.2 (DOUT), D116.4 (DIN)
unnamed: D116.2 (DOUT), D117.4 (DIN)
unnamed: D117.2 (DOUT), D118.4 (DIN)
unnamed: D154.2 (DOUT), D155.4 (DIN)
unnamed: D155.2 (DOUT), D156.4 (DIN)
unnamed: D156.2 (DOUT), D157.4 (DIN)
unnamed: D157.2 (DOUT), D158.4 (DIN)
unnamed: D158.2 (DOUT), D159.4 (DIN)
unnamed: D159.2 (DOUT), D160.4 (DIN)
unnamed: D238.2 (DOUT), D239.4 (DIN)
unnamed: D239.2 (DOUT), D240.4 (DIN)
unnamed: D240.2 (DOUT), D241.4 (DIN)
unnamed: D241.2 (DOUT), D242.4 (DIN)
unnamed: D242.2 (DOUT), D243.4 (DIN)
unnamed: D243.2 (DOUT), D244.4 (DIN)
unnamed: D245.2 (DOUT), D246.4 (DIN)
unnamed: D246.2 (DOUT), D247.4 (DIN)
unnamed: D247.2 (DOUT), D248.4 (DIN)
unnamed: D248.2 (DOUT), D249.4 (DIN)
unnamed: D249.2 (DOUT), D250.4 (DIN)
unnamed: D250.2 (DOUT), D251.4 (DIN)
unnamed: D287.2 (DOUT), D288.4 (DIN)
unnamed: D288.2 (DOUT), D289.4 (DIN)
unnamed: D289.2 (DOUT), D290.4 (DIN)
unnamed: D290.2 (DOUT), D291.4 (DIN)
unnamed: D291.2 (DOUT), D292.4 (DIN)
unnamed: D292.2 (DOUT), D293.4 (DIN)
unnamed: D294.2 (DOUT), D295.4 (DIN)
unnamed: D295.2 (DOUT), D296.4 (DIN)
unnamed: D296.2 (DOUT), D297.4 (DIN)
unnamed: D297.2 (DOUT), D298.4 (DIN)
unnamed: D298.2 (DOUT), D299.4 (DIN)
unnamed: D299.2 (DOUT), D300.4 (DIN)
unnamed: D301.2 (DOUT), D302.4 (DIN)
unnamed: D302.2 (DOUT), D303.4 (DIN)
unnamed: D303.2 (DOUT), D304.4 (DIN)
unnamed: D304.2 (DOUT), D305.4 (DIN)
unnamed: D305.2 (DOUT), D306.4 (DIN)
unnamed: D306.2 (DOUT), D307.4 (DIN)
unnamed: D308.2 (DOUT), D309.4 (DIN)
unnamed: D309.2 (DOUT), D310.4 (DIN)
unnamed: D310.2 (DOUT), D311.4 (DIN)
unnamed: D311.2 (DOUT), D312.4 (DIN)
unnamed: D312.2 (DOUT), D313.4 (DIN)
unnamed: D313.2 (DOUT), D314.4 (DIN)
unnamed: D315.2 (DOUT), D316.4 (DIN)
unnamed: D316.2 (DOUT), D317.4 (DIN)
unnamed: D317.2 (DOUT), D318.4 (DIN)
unnamed: D318.2 (DOUT), D319.4 (DIN)
unnamed: D319.2 (DOUT), D320.4 (DIN)
unnamed: D320.2 (DOUT), D321.4 (DIN)
unnamed: D322.2 (DOUT), D323.4 (DIN)
unnamed: D323.2 (DOUT), D324.4 (DIN)
unnamed: D324.2 (DOUT), D325.4 (DIN)
unnamed: D325.2 (DOUT), D326.4 (DIN)
unnamed: D326.2 (DOUT), D327.4 (DIN)
unnamed: D327.2 (DOUT), D328.4 (DIN)
unnamed: D329.2 (DOUT), D330.4 (DIN)
unnamed: D330.2 (DOUT), D331.4 (DIN)
unnamed: D331.2 (DOUT), D332.4 (DIN)
unnamed: D332.2 (DOUT), D333.4 (DIN)
unnamed: D333.2 (DOUT), D334.4 (DIN)
unnamed: D334.2 (DOUT), D335.4 (DIN)
unnamed: D336.2 (DOUT), D337.4 (DIN)
unnamed: D337.2 (DOUT), D338.4 (DIN)
unnamed: D338.2 (DOUT), D339.4 (DIN)
unnamed: D339.2 (DOUT), D340.4 (DIN)
unnamed: D340.2 (DOUT), D341.4 (DIN)
unnamed: D341.2 (DOUT), D342.4 (DIN)

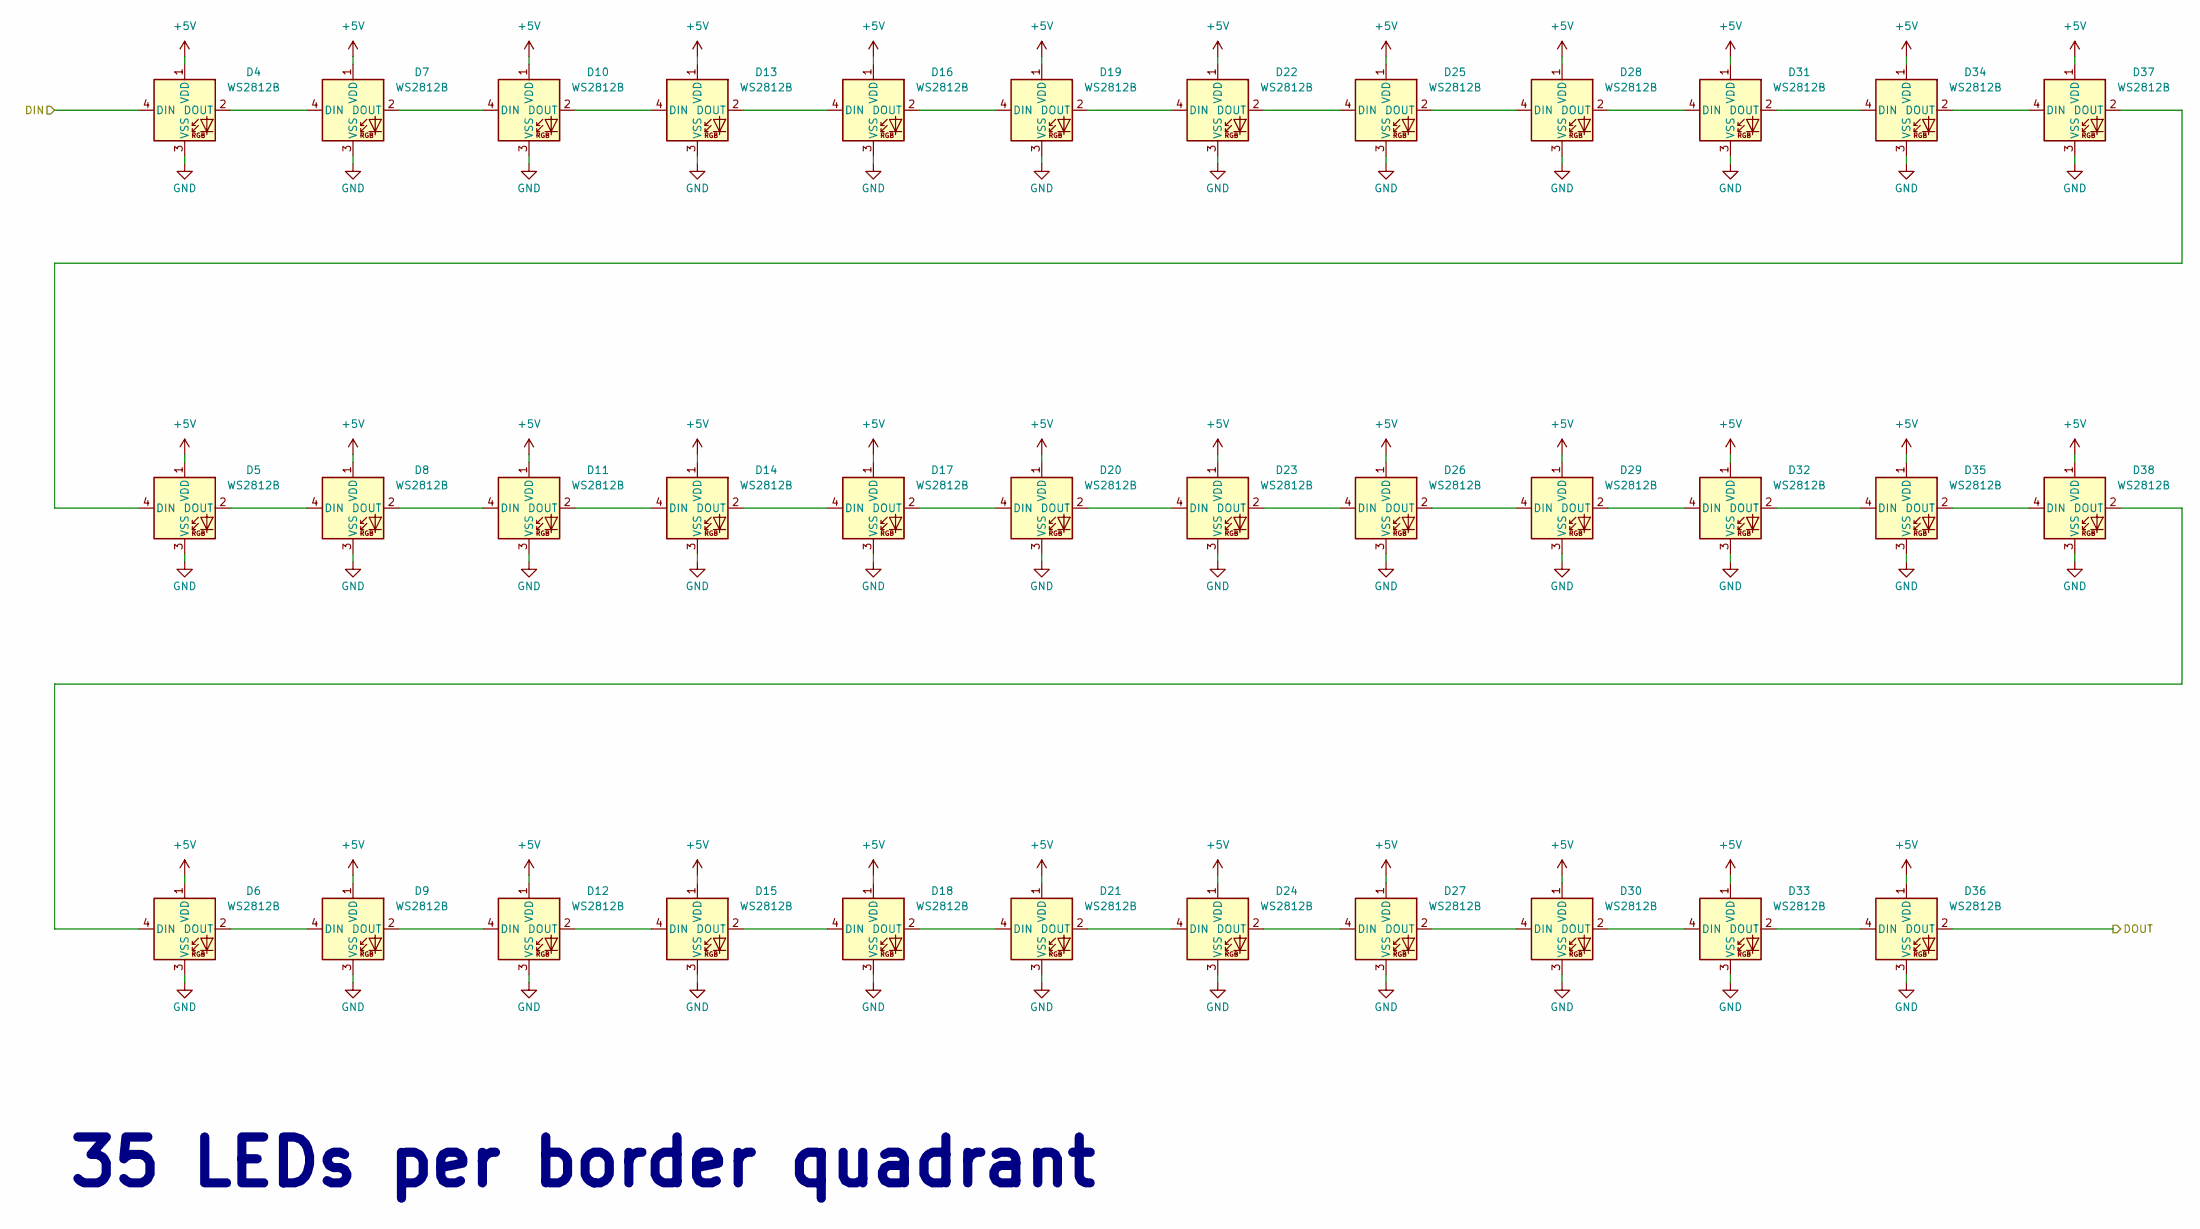
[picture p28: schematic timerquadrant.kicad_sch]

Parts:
D4, D5, D6, D7, D8, D9, D10, D11, D12, D13, D14, D15, D16, D17, D18, D19, D20, D21, D22, D23, D24, D25, D26, D27, D28, D29, D30, D31, D32, D33, D34, D35, D36, D37, D38: WS2812B; LED_WS2812B_PLCC4_5.0x5.0mm_P3.2mm; LCSC C2843785

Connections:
+5V: D4.1 (VDD), D5.1 (VDD), D6.1 (VDD), D7.1 (VDD), D8.1 (VDD), D9.1 (VDD), D10.1 (VDD), D11.1 (VDD), D12.1 (VDD), D13.1 (VDD), D14.1 (VDD), D15.1 (VDD), D16.1 (VDD), D17.1 (VDD), D18.1 (VDD), D19.1 (VDD), D20.1 (VDD), D21.1 (VDD), D22.1 (VDD), D23.1 (VDD), D24.1 (VDD), D25.1 (VDD), D26.1 (VDD), D27.1 (VDD), D28.1 (VDD), D29.1 (VDD), D30.1 (VDD), D31.1 (VDD), D32.1 (VDD), D33.1 (VDD), D34.1 (VDD), D35.1 (VDD), D36.1 (VDD), D37.1 (VDD), D38.1 (VDD); also elsewhere on the board
/TimerBorder/DOUT: D36.2 (DOUT); also elsewhere on the board
/TimerBorder/TimerQuadrant/DOUT: D4.4 (DIN); also elsewhere on the board
GND: D4.3 (VSS), D5.3 (VSS), D6.3 (VSS), D7.3 (VSS), D8.3 (VSS), D9.3 (VSS), D10.3 (VSS), D11.3 (VSS), D12.3 (VSS), D13.3 (VSS), D14.3 (VSS), D15.3 (VSS), D16.3 (VSS), D17.3 (VSS), D18.3 (VSS), D19.3 (VSS), D20.3 (VSS), D21.3 (VSS), D22.3 (VSS), D23.3 (VSS), D24.3 (VSS), D25.3 (VSS), D26.3 (VSS), D27.3 (VSS), D28.3 (VSS), D29.3 (VSS), D30.3 (VSS), D31.3 (VSS), D32.3 (VSS), D33.3 (VSS), D34.3 (VSS), D35.3 (VSS), D36.3 (VSS), D37.3 (VSS), D38.3 (VSS); also elsewhere on the board
unnamed: D4.2 (DOUT), D7.4 (DIN)
unnamed: D5.2 (DOUT), D8.4 (DIN)
unnamed: D6.2 (DOUT), D9.4 (DIN)
unnamed: D7.2 (DOUT), D10.4 (DIN)
unnamed: D10.2 (DOUT), D13.4 (DIN)
unnamed: D8.2 (DOUT), D11.4 (DIN)
unnamed: D11.2 (DOUT), D14.4 (DIN)
unnamed: D9.2 (DOUT), D12.4 (DIN)
unnamed: D12.2 (DOUT), D15.4 (DIN)
unnamed: D13.2 (DOUT), D16.4 (DIN)
unnamed: D14.2 (DOUT), D17.4 (DIN)
unnamed: D15.2 (DOUT), D18.4 (DIN)
unnamed: D16.2 (DOUT), D19.4 (DIN)
unnamed: D17.2 (DOUT), D20.4 (DIN)
unnamed: D18.2 (DOUT), D21.4 (DIN)
unnamed: D19.2 (DOUT), D22.4 (DIN)
unnamed: D20.2 (DOUT), D23.4 (DIN)
unnamed: D21.2 (DOUT), D24.4 (DIN)
unnamed: D22.2 (DOUT), D25.4 (DIN)
unnamed: D23.2 (DOUT), D26.4 (DIN)
unnamed: D24.2 (DOUT), D27.4 (DIN)
unnamed: D25.2 (DOUT), D28.4 (DIN)
unnamed: D26.2 (DOUT), D29.4 (DIN)
unnamed: D27.2 (DOUT), D30.4 (DIN)
unnamed: D28.2 (DOUT), D31.4 (DIN)
unnamed: D29.2 (DOUT), D32.4 (DIN)
unnamed: D30.2 (DOUT), D33.4 (DIN)
unnamed: D31.2 (DOUT), D34.4 (DIN)
unnamed: D32.2 (DOUT), D35.4 (DIN)
unnamed: D33.2 (DOUT), D36.4 (DIN)
unnamed: D34.2 (DOUT), D37.4 (DIN)
unnamed: D35.2 (DOUT), D38.4 (DIN)
unnamed: D5.4 (DIN), D37.2 (DOUT)
unnamed: D6.4 (DIN), D38.2 (DOUT)

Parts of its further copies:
D252, D253, D254, D255, D256, D257, D258, D259, D260, D261, D262, D263, D264, D265, D266, D267, D268, D269, D270, D271, D272, D273, D274, D275, D276, D277, D278, D279, D280, D281, D282, D283, D284, D285, D286: WS2812B; LED_WS2812B_PLCC4_5.0x5.0mm_P3.2mm; LCSC C2843785

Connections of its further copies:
+5V: D252.1 (VDD), D253.1 (VDD), D254.1 (VDD), D255.1 (VDD), D256.1 (VDD), D257.1 (VDD), D258.1 (VDD), D259.1 (VDD), D260.1 (VDD), D261.1 (VDD), D262.1 (VDD), D263.1 (VDD), D264.1 (VDD), D265.1 (VDD), D266.1 (VDD), D267.1 (VDD), D268.1 (VDD), D269.1 (VDD), D270.1 (VDD), D271.1 (VDD), D272.1 (VDD), D273.1 (VDD), D274.1 (VDD), D275.1 (VDD), D276.1 (VDD), D277.1 (VDD), D278.1 (VDD), D279.1 (VDD), D280.1 (VDD), D281.1 (VDD), D282.1 (VDD), D283.1 (VDD), D284.1 (VDD), D285.1 (VDD), D286.1 (VDD); also elsewhere on the board
/TimerBorder/TimerQuadrant/DOUT: D284.2 (DOUT); also elsewhere on the board
BORDER_LEDS: D252.4 (DIN); also elsewhere on the board
GND: D252.3 (VSS), D253.3 (VSS), D254.3 (VSS), D255.3 (VSS), D256.3 (VSS), D257.3 (VSS), D258.3 (VSS), D259.3 (VSS), D260.3 (VSS), D261.3 (VSS), D262.3 (VSS), D263.3 (VSS), D264.3 (VSS), D265.3 (VSS), D266.3 (VSS), D267.3 (VSS), D268.3 (VSS), D269.3 (VSS), D270.3 (VSS), D271.3 (VSS), D272.3 (VSS), D273.3 (VSS), D274.3 (VSS), D275.3 (VSS), D276.3 (VSS), D277.3 (VSS), D278.3 (VSS), D279.3 (VSS), D280.3 (VSS), D281.3 (VSS), D282.3 (VSS), D283.3 (VSS), D284.3 (VSS), D285.3 (VSS), D286.3 (VSS); also elsewhere on the board
unnamed: D252.2 (DOUT), D255.4 (DIN)
unnamed: D253.4 (DIN), D285.2 (DOUT)
unnamed: D253.2 (DOUT), D256.4 (DIN)
unnamed: D254.4 (DIN), D286.2 (DOUT)
unnamed: D254.2 (DOUT), D257.4 (DIN)
unnamed: D255.2 (DOUT), D258.4 (DIN)
unnamed: D256.2 (DOUT), D259.4 (DIN)
unnamed: D257.2 (DOUT), D260.4 (DIN)
unnamed: D258.2 (DOUT), D261.4 (DIN)
unnamed: D259.2 (DOUT), D262.4 (DIN)
unnamed: D260.2 (DOUT), D263.4 (DIN)
unnamed: D261.2 (DOUT), D264.4 (DIN)
unnamed: D262.2 (DOUT), D265.4 (DIN)
unnamed: D263.2 (DOUT), D266.4 (DIN)
unnamed: D264.2 (DOUT), D267.4 (DIN)
unnamed: D265.2 (DOUT), D268.4 (DIN)
unnamed: D266.2 (DOUT), D269.4 (DIN)
unnamed: D267.2 (DOUT), D270.4 (DIN)
unnamed: D268.2 (DOUT), D271.4 (DIN)
unnamed: D269.2 (DOUT), D272.4 (DIN)
unnamed: D270.2 (DOUT), D273.4 (DIN)
unnamed: D271.2 (DOUT), D274.4 (DIN)
unnamed: D272.2 (DOUT), D275.4 (DIN)
unnamed: D273.2 (DOUT), D276.4 (DIN)
unnamed: D274.2 (DOUT), D277.4 (DIN)
unnamed: D275.2 (DOUT), D278.4 (DIN)
unnamed: D276.2 (DOUT), D279.4 (DIN)
unnamed: D277.2 (DOUT), D280.4 (DIN)
unnamed: D278.2 (DOUT), D281.4 (DIN)
unnamed: D279.2 (DOUT), D282.4 (DIN)
unnamed: D280.2 (DOUT), D283.4 (DIN)
unnamed: D281.2 (DOUT), D284.4 (DIN)
unnamed: D282.2 (DOUT), D285.4 (DIN)
unnamed: D283.2 (DOUT), D286.4 (DIN)

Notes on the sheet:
35 LEDs per border quadrant

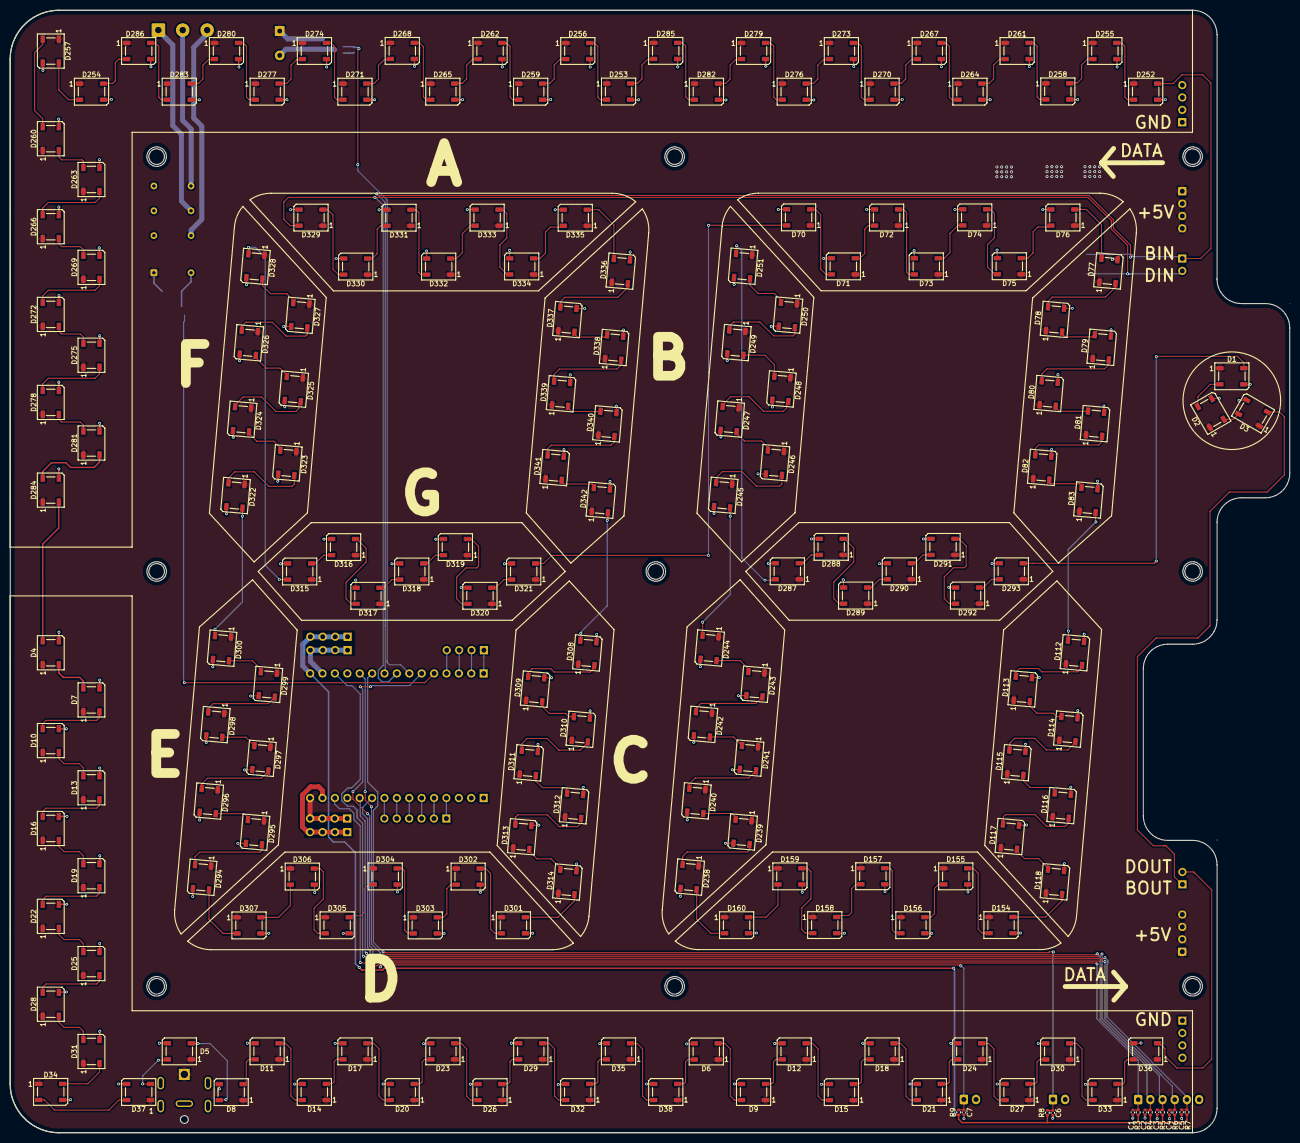
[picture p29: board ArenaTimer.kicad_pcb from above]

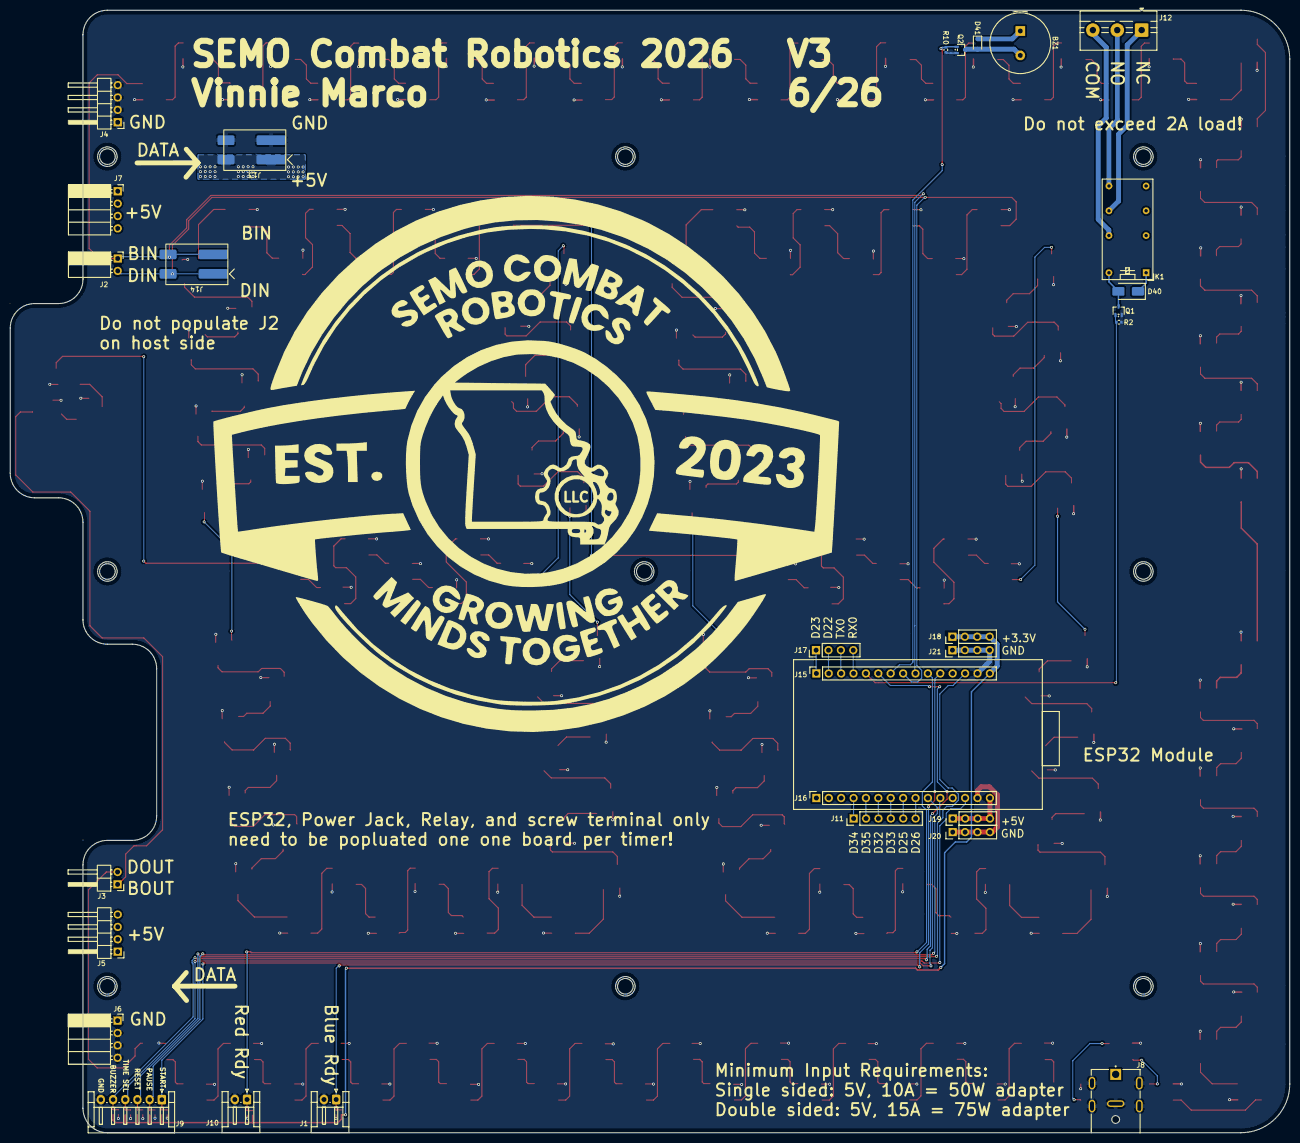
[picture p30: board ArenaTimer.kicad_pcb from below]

Board: 2 copper layers, 262.2 x 230.0 mm, 223 parts (29 on the bottom side), 200 nets.

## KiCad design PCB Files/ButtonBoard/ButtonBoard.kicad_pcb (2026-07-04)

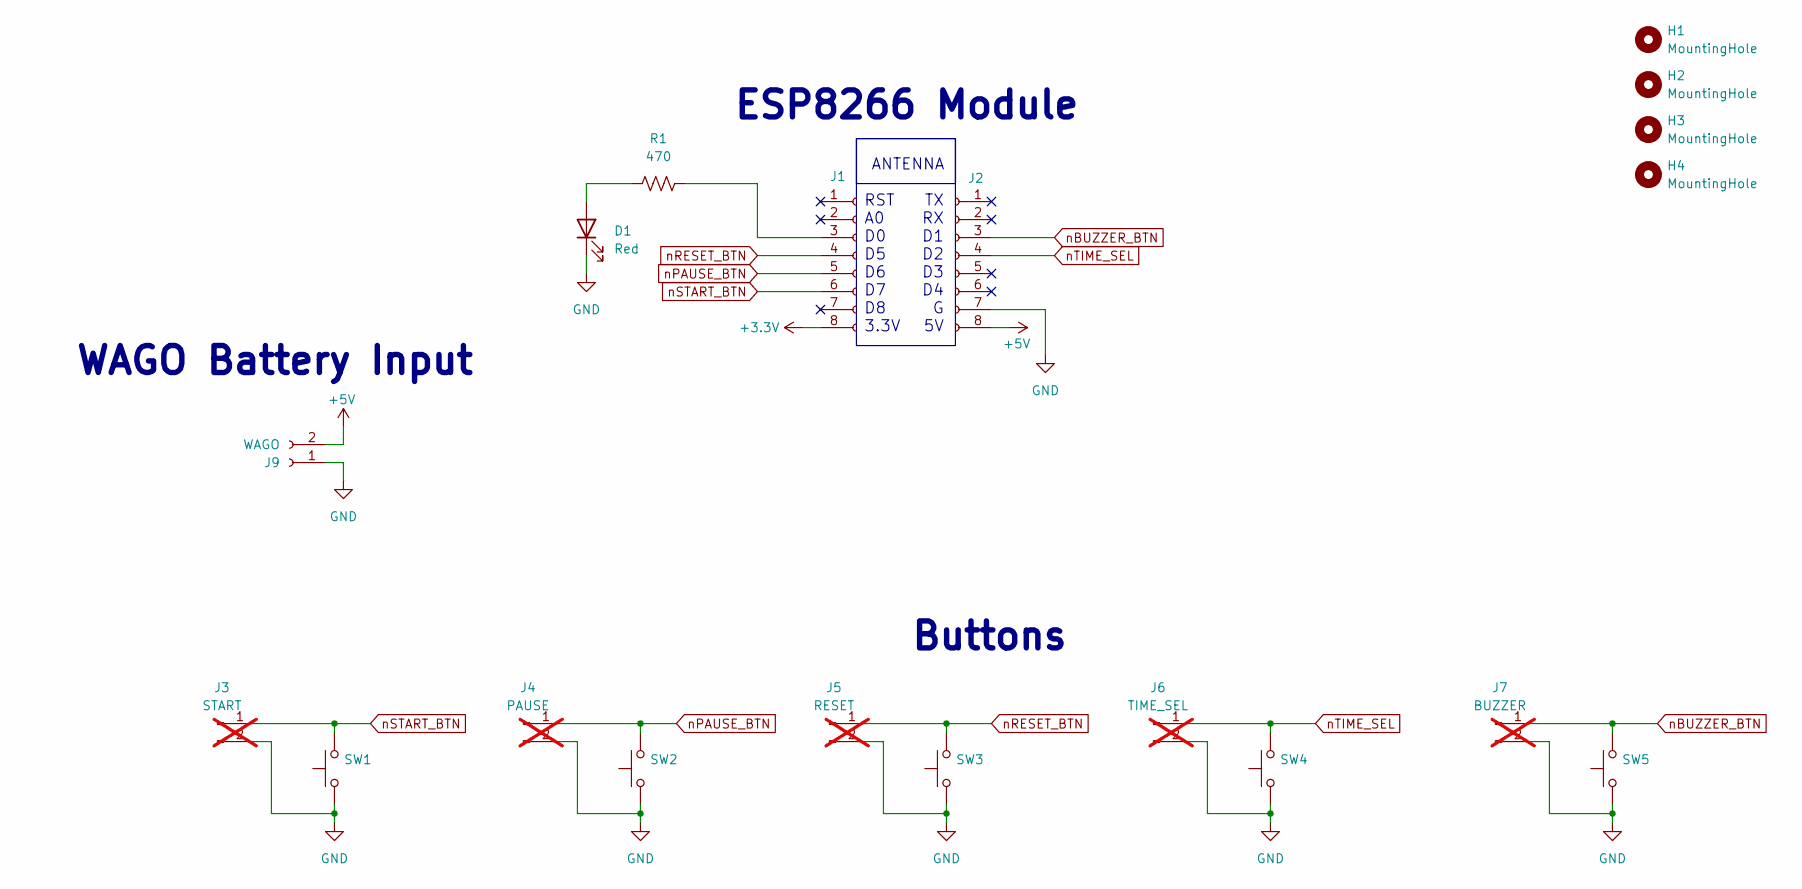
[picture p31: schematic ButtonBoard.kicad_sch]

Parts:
D1: Red; LED_0603_1608Metric; LCSC C2286
H1, H2, H3, H4: MountingHole; MountingHole_3.2mm_M3
J1, J2: Conn_01x08_Socket; PinSocket_1x08_P2.54mm_Vertical; LCSC C42431840
J3: START; PinHeader_1x02_P2.54mm_Vertical; not fitted
J4: PAUSE; PinHeader_1x02_P2.54mm_Vertical; not fitted
J5: RESET; PinHeader_1x02_P2.54mm_Vertical; not fitted
J6: TIME_SEL; PinHeader_1x02_P2.54mm_Vertical; not fitted
J7: BUZZER; PinHeader_1x02_P2.54mm_Vertical; not fitted
J9: WAGO; 2060-452_998-404; LCSC C2765055
R1: 470; R_0603_1608Metric; LCSC C23179
SW1: START; SW_PUSH-12mm; LCSC C2888699
SW2: PAUSE; SW_PUSH-12mm; LCSC C2888699
SW3: RESET; SW_PUSH-12mm; LCSC C2888699
SW4: TIME_SEL; SW_PUSH-12mm; LCSC C2888699
SW5: BUZZER; SW_PUSH-12mm; LCSC C2888699

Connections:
+3.3V: J1.8
+5V: J2.8, J9.2
GND: D1.1 (K), J2.7, J3.2, J4.2, J5.2, J6.2, J7.2, J9.1, SW1.1, SW2.1, SW3.1, SW4.1, SW5.1
unnamed: D1.2 (A), R1.1
unnamed: J1.3, R1.2
nBUZZER_BTN: J2.3, J7.1, SW5.2
nPAUSE_BTN: J1.5, J4.1, SW2.2
nRESET_BTN: J1.4, J5.1, SW3.2
nSTART_BTN: J1.6, J3.1, SW1.2
nTIME_SEL: J2.4, J6.1, SW4.2

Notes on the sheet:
ESP8266 Module
Buttons
RST A0 D0 D5 D6 D7 D8 3.3V
WAGO Battery Input
ANTENNA
TX RX D1 D2 D3 D4 G 5V

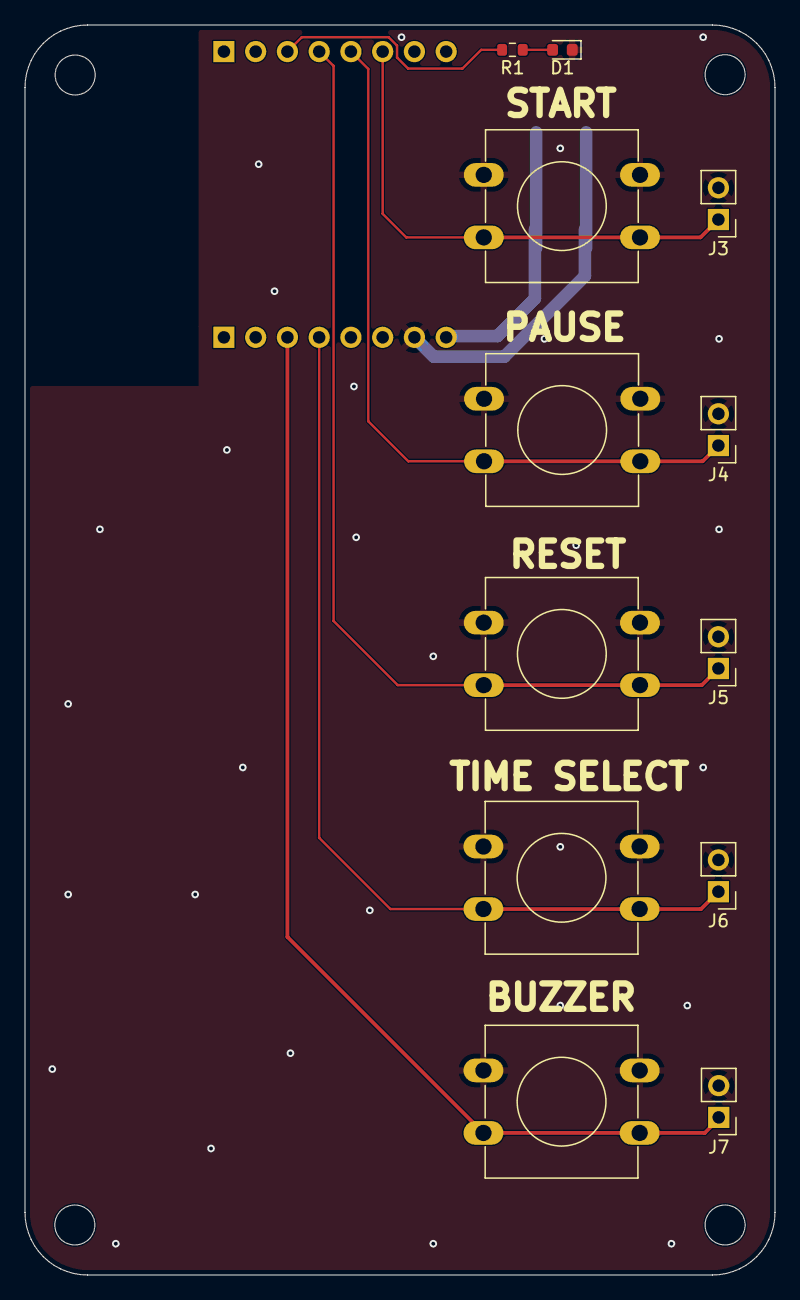
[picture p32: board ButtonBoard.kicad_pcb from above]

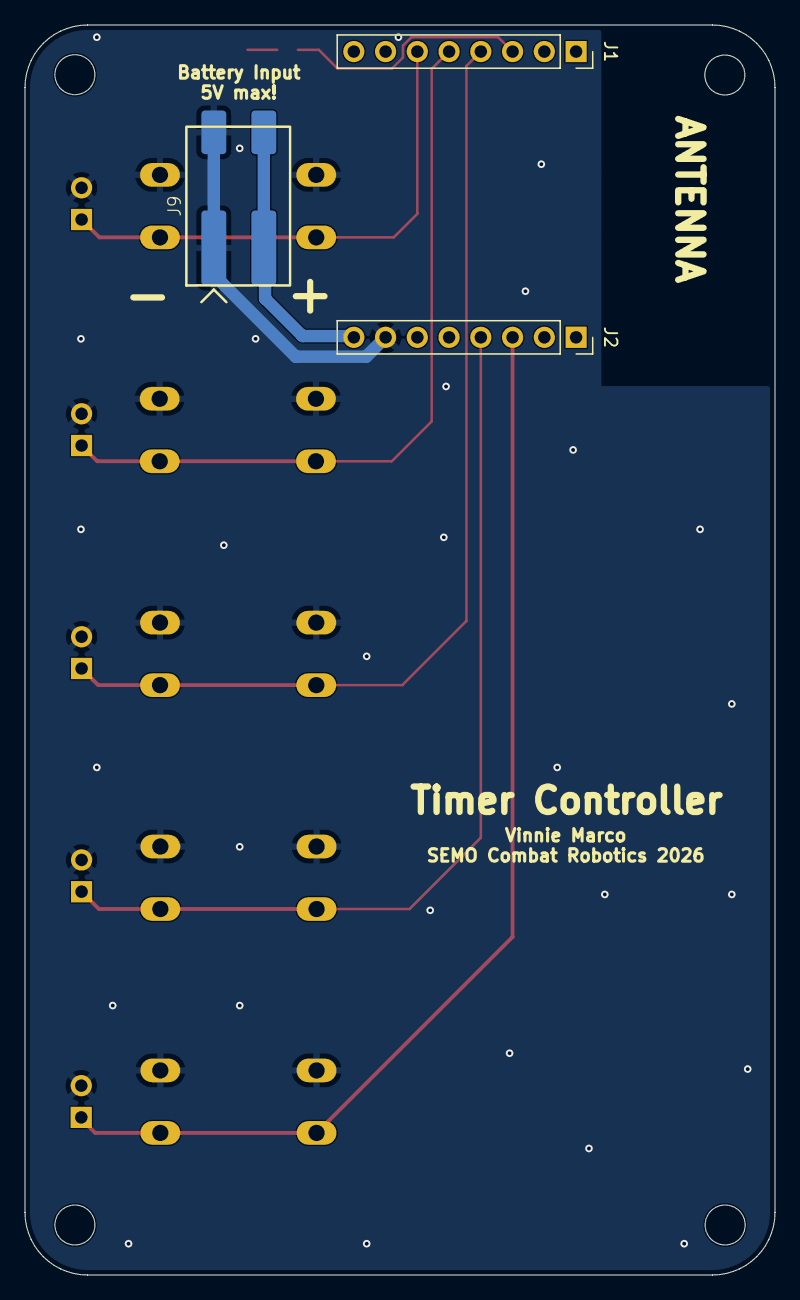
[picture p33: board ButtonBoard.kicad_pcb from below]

Board: 2 copper layers, 60.0 x 100.0 mm, 19 parts (3 on the bottom side), 9 nets.

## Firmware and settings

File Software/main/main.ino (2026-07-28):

#include <WiFi.h>
#include <WebServer.h>
#include <HTTPClient.h>
#include "WebSocketsServer.h"
#include "browser.h"
#include "config.h"
#include "display.h"
#include "timerLogic.h"
#include <queue>
#include <ElegantOTA.h>

std::queue<String> commandQueue;
portMUX_TYPE queueMux = portMUX_INITIALIZER_UNLOCKED;

void queueCommand(String cmd) {
    portENTER_CRITICAL(&queueMux);
    commandQueue.push(cmd);
    portEXIT_CRITICAL(&queueMux);
}

Preferences preferences;

// Instantiate the objects here
WebServer server(80);
WebSocketsServer webSocket = WebSocketsServer(81);

const char* apSSID = "MACROTimer"; // adjusted SSID & passwords 07/27/2026 -N
const char* apPassword = "MACROTimerPassword"; //

int countdown_time = 120; // Default to 2 minutes (120 seconds)
int current_time = countdown_time;
bool timeSelState = false;
bool blueReady = false;
bool redReady = false;
bool readyRequired = true; // default to requiring ready-up //adjusted for basic logic 07/27/2026 -N

bool border_toggle = 1;

// ESP-NOW Globals
bool pairingMode = false;
uint8_t redMAC[6], blueMAC[6], judgeMAC[6];
bool redPaired = false, bluePaired = false, judgePaired = false;
struct_message incoming;

int countdown = 5; //number of seconds until match start // adjusted to 5s from 3s per ref request 

int scrollIndex = 0;
unsigned long lastScrollTime = 0;
volatile bool needsLEDUpdate = false;
unsigned long startAttemptTime = 0;

int currentState = CONNECTING;

bool displayInverted = false;

bool tapoutEnabled = true;
bool tapoutInitiatorIsBlue = true;

bool audioEnabled = true;
bool remoteAudioEnabled = true;
uint8_t audioOutputSelect = 0; // 0 = Buzzer, 1 = Relay
uint32_t beepEndTime = 0;
bool beepActive = false;

// main.ino Globals
CRGB digitColor = CRGB::Red; // Default
uint8_t systemBrightness = 127;

bool isDoubleSided = true;

void OnDataRecv(const esp_now_recv_info *info, const uint8_t *data, int len) {
  memcpy(&incoming, data, sizeof(incoming)); 
  uint8_t* mac = info->src_addr; 

  // If it's a buzzer hold packet, we BYPASS the 300ms cooldown so we track the stream.
  static unsigned long lastPacketTime = 0;
  if (incoming.buttonID != 5) { 
      if (millis() - lastPacketTime < 300) return;
      lastPacketTime = millis();
      Serial.printf("[ESP-NOW] Role: %s | Button: %d\n", incoming.deviceType, incoming.buttonID);
  }

  if (pairingMode) { 
      saveRole(mac, String(incoming.deviceType)); 
      pairingMode = false; 
      return; 
  }

  // --- WIRELESS REMOTE LOGIC ---
  if (strcmp(incoming.deviceType, "RedReady") == 0) { 
    // Validate that this packet came from the paired Red Remote
    if (redPaired && memcmp(mac, redMAC, 6) == 0) {
        if (currentState == RUNNING) { 
            processCommand("tapoutRed");
        } else {
            setTeamReady("Red");
        }
    } else {
        Serial.println("[ESP-NOW REJECT] Unpaired or unauthorized Red packet source.");
    }
  } 
  else if (strcmp(incoming.deviceType, "BlueReady") == 0) { 
    // Validate that this packet came from the paired Blue Remote
    if (bluePaired && memcmp(mac, blueMAC, 6) == 0) {
        if (currentState == RUNNING) { 
            processCommand("tapoutBlue");
        } else {
            setTeamReady("Blue");
        }
    } else {
        Serial.println("[ESP-NOW REJECT] Unpaired or unauthorized Blue packet source.");
    }
  }
  else if (strcmp(incoming.deviceType, "Judge") == 0) { 
    // Validate that this packet came from the paired Judge Remote
    if (judgePaired && memcmp(mac, judgeMAC, 6) == 0) {
        switch(incoming.buttonID) { 
            case 1: queueCommand("start");   break; 
            case 2: queueCommand("pause");   break; 
            case 3: queueCommand("reset");   break; 
            case 4: queueCommand("switch");  break;
            case 5: 
                if (audioEnabled && remoteAudioEnabled) {
                    triggerBeep(250);
                }
                break;
        }
    } else {
        Serial.println("[ESP-NOW REJECT] Unpaired or unauthorized Judge packet source.");
    }
  }
}

void saveRole(const uint8_t *mac, String role) {
    preferences.begin("bot-timer", false); 
    
    if (role == "RedReady") {
        memcpy(redMAC, mac, 6);
        preferences.putBytes("redMAC", mac, 6);
        redPaired = true;
    } else if (role == "BlueReady") {
        memcpy(blueMAC, mac, 6);
        preferences.putBytes("blueMAC", mac, 6);
        bluePaired = true;
    } else if (role == "Judge") {
        memcpy(judgeMAC, mac, 6);
        preferences.putBytes("judgeMAC", mac, 6);
        judgePaired = true;
    }
    
    preferences.end();
    Serial.println("[BIND] " + role + " paired successfully.");
}

void initNetwork() {
    connectWiFi();

    server.on("/", handleRoot);
    server.on("/control", handleControl);
    server.on("/settime", handleSetTime);
    server.on("/setwifi", handleSetWiFi);
    
    server.on("/pair", []() { 
        pairingMode = true; 
        Serial.println("[SYSTEM] Pairing Mode Active");
        server.send(200, "text/plain", "Pairing Mode Active"); 
    });

    server.on("/clear_remotes", []() {
        clearRemotes();
        server.send(200, "text/plain", "Remotes Wiped");
    });

    server.on("/status", []() {
      String json = "{";
      json += "\"pairing\":" + String(pairingMode ? "true" : "false") + ",";
      json += "\"readyRequired\":" + String(readyRequired ? "true" : "false") + ",";
      json += "\"tapoutEnabled\":" + String(tapoutEnabled ? "true" : "false") + ",";
      json += "\"audioEnabled\":" + String(audioEnabled ? "true" : "false") + ",";
      json += "\"remoteAudioEnabled\":" + String(remoteAudioEnabled ? "true" : "false") + ",";
      json += "\"audioOutput\":" + String(audioOutputSelect) + ",";
        
      json += "\"state\":\"";
      if (currentState == CLOCK_MODE) json += "CLOCK_MODE";
      else if (currentState == RUNNING) json += "RUNNING";
      else if (currentState == PAUSED) json += "PAUSED";
      else if (currentState == PRE_COUNTDOWN_LOOP) json += "PRE_COUNTDOWN_LOOP";
      else if (currentState == FINISHED) json += "FINISHED";
      else if (currentState == TAPOUT) json += "TAPOUT";
      else json += "IDLE";
      json += "\",";

      json += "\"tapoutBlue\":" + String(tapoutInitiatorIsBlue ? "true" : "false") + ",";
      json += "\"red\":" + String(redPaired ? "true" : "false") + ",";
      json += "\"blue\":" + String(bluePaired ? "true" : "false") + ",";
      json += "\"judge\":" + String(judgePaired ? "true" : "false") + ",";
      json += "\"brightness\":" + String(systemBrightness) + ",";
      json += "\"displayInverted\":" + String(displayInverted ? "true" : "false") + ",";

      char hexColor[7];
      snprintf(hexColor, sizeof(hexColor), "%02X%02X%02X", digitColor.r, digitColor.g, digitColor.b);
      json += "\"digitColor\":\"" + String(hexColor) + "\",";
      
      int minutes = current_time / 60;
      int seconds = current_time % 60;
      char timeBuf[6];
      snprintf(timeBuf, sizeof(timeBuf), "%02d:%02d", minutes, seconds);
      json += "\"currentTime\":\"" + String(timeBuf) + "\"";
      json += "}"; 
      
      server.send(200, "application/json", json);
    });

    server.on("/setcolor", []() {
        if (currentState == RUNNING || currentState == PAUSED || currentState == PRE_COUNTDOWN_LOOP) {
            server.send(403, "text/plain", "Locked during match");
            return;
        }

        String hexStr = server.arg("hex");
        uint32_t hex = strtol(hexStr.c_str(), NULL, 16);
        
        uint8_t r = (hex >> 16) & 0xFF;
        uint8_t g = (hex >> 8)  & 0xFF;
        uint8_t b = hex & 0xFF;

        if (r > 180 && g > 180 && b > 180) {
            Serial.println("[SAFETY] Blinding near-white color detected. Saving and applying as a soft gray floor.");
            hex = 0x323232;
        }

        digitColor = CRGB(hex);
        
        preferences.begin("settings", false);
        preferences.putUInt("digitColor", hex);
        preferences.end();
        
        updateLEDs();

        server.send(200, "text/plain", "Color Processed & Saved");
    });

    server.on("/setbrightness", []() {
      if (currentState == RUNNING || currentState == PAUSED || currentState == PRE_COUNTDOWN_LOOP) {
          server.send(403, "text/plain", "Locked during match");
          return;
      }
      int requestedVal = server.arg("val").toInt();
      systemBrightness = constrain(requestedVal, 10, 230);

      preferences.begin("settings", false);
      preferences.putUChar("brightness", systemBrightness);
      preferences.end();

      FastLED.setBrightness(systemBrightness);
      needsLEDUpdate = true;

      server.send(200, "text/plain", "Brightness Set");
    });

    server.on("/synctime", []() {
        if (currentState != IDLE && currentState != CLOCK_MODE) {
            server.send(403, "text/plain", "Timer is active!");
            return;
        }
        int hour = server.arg("h").toInt();
        int minute = server.arg("m").toInt();
        int s = server.arg("s").toInt();

        struct tm tm;
        tm.tm_hour = hour; tm.tm_min = minute; tm.tm_sec = s;
        tm.tm_year = 2026 - 1900; tm.tm_mon = 4; tm.tm_mday = 10;
        time_t t = mktime(&tm);
        struct timeval now = { .tv_sec = t };
        settimeofday(&now, NULL);
        
        currentState = CLOCK_MODE;

        preferences.begin("settings", false);
        preferences.putBool("clockActive", true);
        preferences.end();


        for (int i = 0; i < BORDER_LED_COUNT; i++) setBorderLEDs(i, CRGB::Black);
        for (int i = 0; i < DIGIT_LED_COUNT; i++) setDigitLEDs(i, CRGB::Black);

        if (hour == 0) hour = 12;
        if (hour > 12) hour -= 12;

        if (!displayInverted) {
            setDigit(hour / 10, 0, false);
            setDigit(hour % 10, 49, false);
            setColon();
            setDigit(minute / 10, 150, true);
            setDigit(minute % 10, 101, true);
        } else {
            setDigit(minute % 10, 0, false);
            setDigit(minute / 10, 49, false);
            setColon();
            setDigit(hour % 10, 150, true);
            setDigit(hour / 10, 101, true);
        }

        for (int i = 0; i < BORDER_LED_COUNT; i++)
            setBorderLEDs(i, ORANGE); 

        applyDoubleSidedMirror();
        FastLED.show();
        needsLEDUpdate = false;

        server.send(200, "text/plain", "Clock Seeded");
    });

    server.on("/flip", []() {
      displayInverted = !displayInverted;
      preferences.begin("settings", false);
      preferences.putBool("dispInv", displayInverted);
      preferences.end();
      
      needsLEDUpdate = true;
      
      if (currentState == CLOCK_MODE) {
          handleClockMode(); 
      } else {
          updateLEDs();
      }
      
      setBorder();

      server.send(200, "text/plain", displayInverted ? "Inverted" : "Normal");
    });

    server.on("/setaudio", []() {
        if (currentState == RUNNING || currentState == PAUSED || currentState == PRE_COUNTDOWN_LOOP) {
            server.send(403, "text/plain", "Locked during match");
            return;
        }
        
        if (server.hasArg("enabled")) audioEnabled = (server.arg("enabled") == "true");
        if (server.hasArg("remoteEnabled")) remoteAudioEnabled = (server.arg("remoteEnabled") == "true");
        if (server.hasArg("output")) audioOutputSelect = server.arg("output").toInt();

        preferences.begin("settings", false);
        preferences.putBool("audioEnabled", audioEnabled);
        preferences.putBool("remoteAudio", remoteAudioEnabled);
        preferences.putUChar("audioOutput", audioOutputSelect);
        preferences.end();

        server.send(200, "text/plain", "Audio Settings Saved");
    });

    webSocket.onEvent(onWebSocketEvent);
    ElegantOTA.begin(&server);
    webSocket.begin();
    server.begin();
    Serial.println("[SYSTEM] HTTP Server and WebSocket Started");
}

void startAPMode() {
    Serial.println("Starting Access Point mode...");
    WiFi.softAP(apSSID, apPassword);
    Serial.print("AP IP Address: ");
    Serial.println(WiFi.softAPIP());
}

void handleRoot() {
  server.send(200, "text/html", html);
}

void handleControl() {
    String cmd = server.arg("cmd"); 
    Serial.printf("[WEB DEBUG] handleControl received endpoint query! cmd = '%s'\n", cmd.c_str());
    
    if (cmd == "readytoggle") { 
        String state = server.arg("state"); 
        readyRequired = (state == "on"); 
        preferences.begin("settings", false); 
        preferences.putBool("readyRequired", readyRequired); 
        preferences.end(); 

        if(currentState != RUNNING) 
          setBorder(); 
    } 
    else if (cmd == "tapouttoggle") { 
        String state = server.arg("state"); 
        tapoutEnabled = (state == "on"); 
        
        preferences.begin("settings", false); 
        preferences.putBool("tapoutEnabled", tapoutEnabled); 
        preferences.end(); 
        
        Serial.printf("[SYSTEM] Tapout Functionality updated and saved: %s\n", tapoutEnabled ? "ENABLED" : "DISABLED"); 
    } 
    else {
        queueCommand(cmd); 
    }
    server.send(200, "text/plain", "OK"); 
}

void handleSetTime() {
    if (currentState == RUNNING || currentState == PRE_COUNTDOWN_LOOP) {
        server.send(403, "text/plain", "Cannot set time while match is active!");
        return;
    }

    int m = server.arg("m").toInt();
    int s = server.arg("s").toInt();
    
    current_time = (m * 60) + s;
    currentState = IDLE;
    
    updateClient();
    updateLEDs();
    
    server.send(200, "text/plain", "Time Updated");
}

void updateClient() {
  int minutes = current_time / 60;
  int seconds = current_time % 60;
  char buffer[6];
  snprintf(buffer, sizeof(buffer), "%02d:%02d", minutes, seconds);
  webSocket.broadcastTXT(buffer);
}

void onWebSocketEvent(uint8_t num, WStype_t type, uint8_t * payload, size_t length) {}

void handleSetWiFi() {
    String ssid = server.arg("ssid");
    String pass = server.arg("pass");
    
    if (ssid.length() > 0 && pass.length() > 0) {
        preferences.begin("wifi", false);
        preferences.putString("ssid", ssid);
        preferences.putString("pass", pass);
        preferences.end();
        
        server.send(200, "text/html", "<h1>WiFi Credentials Saved! Rebooting...</h1>");
        delay(3000);
        ESP.restart();
    } else {
        server.send(200, "text/html", "<h1>Invalid Input - Both SSID and Password are required</h1>");
    }
}

void connectWiFi() {
    preferences.begin("wifi", true);
    String ssid = preferences.getString("ssid", "");
    String pass = preferences.getString("pass", "");
    preferences.end();
    
    if (ssid.length() == 0 || ssid == "Disconnected") {
        startAPMode();
        return;
    }
    
    WiFi.begin(ssid.c_str(), pass.c_str());
    startAttemptTime = millis(); 
    currentState = CONNECTING;   
}

void checkWiFiConnection() {
    if (currentState != CONNECTING) return;

    bool connectionFinished = false;
    bool connectionFailed = false;

    if (WiFi.status() == WL_CONNECTED) {
        static bool serversStarted = false;
        if (!serversStarted) {
            server.begin();
            webSocket.begin();
            webSocket.onEvent(onWebSocketEvent);
            
            Serial.println("\n[NETWORK] WiFi Connected successfully!");
            Serial.print("[NETWORK] Local IP Address: http://");
            Serial.println(WiFi.localIP());

            configTime(0, 0, "pool.ntp.org", "time.nist.gov");
            setenv("TZ", "CST6CDT,M3.2.0,M11.1.0", 1);
            tzset();

            serversStarted = true;
        }
        connectionFinished = true;
    } 
    else if (millis() - startAttemptTime > 15000) {
        startAPMode();
        preferences.begin("settings", false);
        preferences.putBool("clockActive", false);
        preferences.end();
        connectionFinished = true;
        connectionFailed = true;
    }

    if (connectionFinished) {
        preferences.begin("settings", true);
        bool clockActive = preferences.getBool("clockActive", false);
        preferences.end();

        if (clockActive && !connectionFailed) {
            currentState = CLOCK_MODE;

            Serial.println("[SYSTEM] Performing sequential inline timezone detection...");
            HTTPClient http;
            http.setTimeout(2500); 
            http.begin("http://worldtimeapi.org/api/ip.txt");
            
            int httpCode = http.GET();
            String posixString = "";
            
            if (httpCode == HTTP_CODE_OK) {
                String payload = http.getString();
                int tzOffsetIdx = payload.indexOf("utc_offset: ");
                
                if (tzOffsetIdx != -1) {
                    int startOffset = tzOffsetIdx + 12;
                    int endOffset = payload.indexOf('\n', startOffset);
                    String rawOffset = payload.substring(startOffset, endOffset);
                    rawOffset.trim();
                    
                    int hoursOffset = rawOffset.substring(1, 3).toInt();
                    char sign = rawOffset.charAt(0);
                    
                    if (sign == '-') {
                        posixString = "GMT" + String(hoursOffset);
                    } else {
                        posixString = "GMT-" + String(hoursOffset);
                    }
                    
                    if (payload.indexOf("America/") != -1) {
                        int dstOffset = hoursOffset - 1;
                        posixString += "GMT+" + String(dstOffset) + ",M3.2.0,M11.1.0";
                    }
                }
            }
            http.end();

            if (posixString.length() > 0) {
                Serial.printf("[SYSTEM] Found region rule inline: %s\n", posixString.c_str());
                setenv("TZ", posixString.c_str(), 1);
                tzset();
            } else {
                Serial.println("[SYSTEM] Network lookup failed or timed out. Falling back to Central Time.");
                setenv("TZ", "CST6CDT,M3.2.0,M11.1.0", 1);
                tzset();
            }

            struct tm timeinfo;
            if (getLocalTime(&timeinfo)) {
                Serial.println("[SYSTEM] Inline clock calibration complete.");
            }

            handleClockMode();
            setBorder();
        } 
        else {
            currentState = IDLE;
            updateLEDs();
            setBorder();
        }

        applyDoubleSidedMirror();
        needsLEDUpdate = true;
        updateClient();
        
    } 
    else if (connectionFailed) {
        Serial.println("[SYSTEM WARNING] WiFi Connection failed! Gating in IDLE mode on Access Point hotspot.");
    }
}

void clearRemotes() {
    Serial.println("[SYSTEM] Wiping remote bindings...");
    
    preferences.begin("bot-timer", false); 
    preferences.remove("redMAC"); 
    preferences.remove("blueMAC"); 
    preferences.remove("judgeMAC");
    preferences.end();
    
    redPaired = false;
    bluePaired = false;
    judgePaired = false;
    
    memset(redMAC, 0, 6);
    memset(blueMAC, 0, 6);
    memset(judgeMAC, 0, 6);
    
    Serial.println("[SYSTEM] All remotes wiped.");
}

void loadSavedSettings() {
    preferences.begin("bot-timer", true); 
    redPaired   = (preferences.getBytes("redMAC", redMAC, 6) == 6); 
    bluePaired  = (preferences.getBytes("blueMAC", blueMAC, 6) == 6); 
    judgePaired = (preferences.getBytes("judgeMAC", judgeMAC, 6) == 6); 
    preferences.end(); 
    
    preferences.begin("settings", true); 
    readyRequired = preferences.getBool("readyRequired", false); 
    timeSelState = preferences.getBool("timeSelState", false); 
    systemBrightness = preferences.getUChar("brightness", 127); 
    displayInverted = preferences.getBool("dispInv", false); 
    tapoutEnabled = preferences.getBool("tapoutEnabled", true); 

    audioEnabled = preferences.getBool("audioEnabled", true);
    remoteAudioEnabled = preferences.getBool("remoteAudio", true);
    audioOutputSelect = preferences.getUChar("audioOutput", 0);
    
    preferences.end(); 
    FastLED.setBrightness(systemBrightness); 
    uint32_t savedColor = preferences.getUInt("digitColor", 0xFF0000); 
    digitColor = CRGB(savedColor); 

    countdown_time = timeSelState ? 180 : 120; 
    current_time = countdown_time; 
}
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
void loop() {
  static uint32_t lastFrameTime = 0;
  uint32_t currentMillis = millis();

  server.handleClient();
  webSocket.loop();
  ElegantOTA.loop(); 

  if (currentMillis - lastFrameTime >= 2) { // from 20ms to 2ms, attempt to catch more of the wifi packets.
    lastFrameTime = currentMillis;

    checkAudioTimeout();

    checkButtons();

    String nextCmd = "";
    portENTER_CRITICAL(&queueMux);
    if (!commandQueue.empty()) {
        nextCmd = commandQueue.front();
        commandQueue.pop();
    }
    portEXIT_CRITICAL(&queueMux);

    if (nextCmd != "") {
        processCommand(nextCmd); 
    }

    switch(currentState) {
      case CONNECTING:
        handleConnectingAnimation();
        checkWiFiConnection();
      break;
      case PRE_COUNTDOWN_INIT:
        startPreCountdown();
      break;
      case PRE_COUNTDOWN_LOOP:
        handlePreCountdownAnimation(); 
      break;
      case RUNNING:
        updateTimer();
      break;
      case PAUSED:
        handlePausedBlink();
      break;
      case FINISHED:
      break;
      case CLOCK_MODE:
        handleClockMode();
      break;
      case TAPOUT:
        handleTapoutAnimation();
      break;
    }

    if (needsLEDUpdate) {
        applyDoubleSidedMirror();
        FastLED.show();
        needsLEDUpdate = false;
    }
  }
}

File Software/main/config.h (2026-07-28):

// will hijack this file to be used as a variable dump (eg. countdown length, mode select, etc)

// countdown go here = 5? i'm crying

#ifndef CONFIG_H
#define CONFIG_H

#include <Arduino.h>
#include <FastLED.h>
#include <Preferences.h>
#include <esp_now.h> // Add this include
#include <time.h>

// Pin assignments
#define RESET_BTN 12
#define PAUSE_BTN 14
#define START_BTN 27
#define TIME_SEL_SW 13
#define LED_BUILTIN 2
#define BLUE_BTN 4
#define RED_BTN 16
#define BUZZ_PIN 18
#define RELAY_PIN 21

// LED pin assignments
#define DIGIT_PIN   5
#define BORDER_PIN  17
#define DIGIT_LED_COUNT 202
#define BORDER_LED_COUNT 140
#define LEFT_BORDER 0
#define RIGHT_BORDER 70
#define ORANGE CRGB(255, 50, 0)

// Strip calculation constants
#define HALF_DIGIT (DIGIT_LED_COUNT / 2)
#define HALF_BORDER (BORDER_LED_COUNT / 2)
#define PHYSICAL_STRIP_LEN (HALF_DIGIT + HALF_BORDER)

// Hardware selection pin (Short to GND for Single-Sided Mode)
#define HW_VARIANT_PIN 22

// Double-sided absolute memory buffer requirement
#define DOUBLE_STRIP_LEN (PHYSICAL_STRIP_LEN * 2)

// Add to Config.h
extern CRGB digitColor;
extern uint8_t systemBrightness;

// Global Objects
extern Preferences preferences;

// Constants
const float scrollInterval = 1000.0 / BORDER_LED_COUNT;
const unsigned long debounceDelay = 200;

// Add the struct definition
typedef struct struct_message {
    char deviceType[15];
    int buttonID;
} __attribute__((packed)) struct_message;

// Add these to your "Global Objects" or "Constants" section
extern bool pairingMode;
extern bool redPaired, bluePaired, judgePaired;

// Add these to Config.h
extern int current_time;
extern bool readyRequired;

extern int countdown_time;
extern bool blueReady;
extern bool redReady;

extern bool displayInverted;

extern bool tapoutEnabled; // Track if tapouts are allowed during a match
extern bool tapoutInitiatorIsBlue;

extern bool audioEnabled;
extern bool remoteAudioEnabled;
extern uint8_t audioOutputSelect; // 0 = Buzzer (Tone), 1 = Relay (Digital Pin)

// Non-blocking beep engine function prototypes
void triggerBeep(uint32_t durationMs);
void checkAudioTimeout();

enum timerState {
    CONNECTING,
    IDLE,
    PRE_COUNTDOWN_INIT,
    PRE_COUNTDOWN_LOOP,
    RUNNING,
    PAUSED,
    FINISHED,
    CLOCK_MODE, 
    TAPOUT
};

extern int currentState;

// Function prototypes for functions defined in other modules
void starPreCountdown(); // Defined in TimerLogic
void updateClient();     // Defined in Network
void updateLEDs();       // Defined in Display
void setBorder();        // Defined in Display

#endif

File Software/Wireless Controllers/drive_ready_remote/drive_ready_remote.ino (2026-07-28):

#include <ESP8266WiFi.h>
#include <espnow.h>

#define Debug

// --- CONFIGURATION ---
const char* DEV_TYPE = "RedReady";//BlueReady or RedReady
uint8_t broadcastAddress[] = {0xFF, 0xFF, 0xFF, 0xFF, 0xFF, 0xFF};

typedef struct struct_message {
    char deviceType[15];
    int buttonID;
} struct_message;

struct_message myData;

void setup() {
    // Start serial quickly for debugging
    # ifdef Debug
        Serial.begin(115200);
        Serial.println("\n[!] Wake detected. Initializing Shotgun Blast...");
    #endif

    // 1. WiFi Prep
    WiFi.mode(WIFI_STA);
    WiFi.disconnect(); 

    int ifinit = esp_now_init();

    delay(30); // our added delay to assist suspected init errors. // 07/27/2026 -N

    if (ifinit != 0) { // from: if (esp_now_init() != 0) { // 07/26/2026
        #ifdef Debug
            Serial.println("ESP-NOW Init Failed");
        #endif

        ESP.deepSleep(0); // Sleep and try again next press
        return;
    }

    esp_now_set_self_role(ESP_NOW_ROLE_CONTROLLER);
    
    // Add the peer initially on Channel 1 (we will update this in the loop)
    esp_now_add_peer(broadcastAddress, ESP_NOW_ROLE_SLAVE, 1, NULL, 0);

    // 2. Prepare the data packet
    strcpy(myData.deviceType, DEV_TYPE);
    myData.buttonID = 1;

    for (int ch = 1; ch <= 11; ch++) {
        wifi_set_channel(ch);
        esp_now_set_peer_channel(broadcastAddress, ch);
        
        // Small internal loop for extra insurance on each channel
        for(int extra = 0; extra < 3; extra++) {
            esp_now_send(broadcastAddress, (uint8_t *) &myData, sizeof(myData));
            delay(2); // very short gap
        }
        #ifdef Debug
            Serial.printf("Blasted Channel %d (3x)\n", ch);
        #endif
    }

    // 4. Mission Complete
    #ifdef Debug
        Serial.println("Sweep complete. Entering Deep Sleep (Infinite).");
    #endif

    // Give the last packet a tiny bit of time to leave the buffer 
    // before we yank the power from the radio.
    delay(50);
    
    // Deep sleep (0) means sleep until the RST pin is pulled LOW
    ESP.deepSleep(0); 
}

void loop() {
    // Unused in Deep Sleep workflow
}

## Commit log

2026-07-04 added all STLs, cad, and CAD. Organized file structure a bit
    [ArenaTimer.kicad_pcb, ArenaTimer.kicad_sch, Bottom_left.stl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]
2026-07-16 Added BOM.md
2026-07-20 Update controller STL files to replace STOP with RESET
    [Timer Remote v21_Timer Remote v21_Body10.stl, Timer Remote v21_Timer Remote v21_Body11.stl, Timer Remote v21_Timer Remote v21_Body12.stl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]
2026-07-27 Basic quality of life changes
    countdown passthrough fix, ready required default, 3s -> 5s countdown.
    [main.ino, timerLogic.cpp]
